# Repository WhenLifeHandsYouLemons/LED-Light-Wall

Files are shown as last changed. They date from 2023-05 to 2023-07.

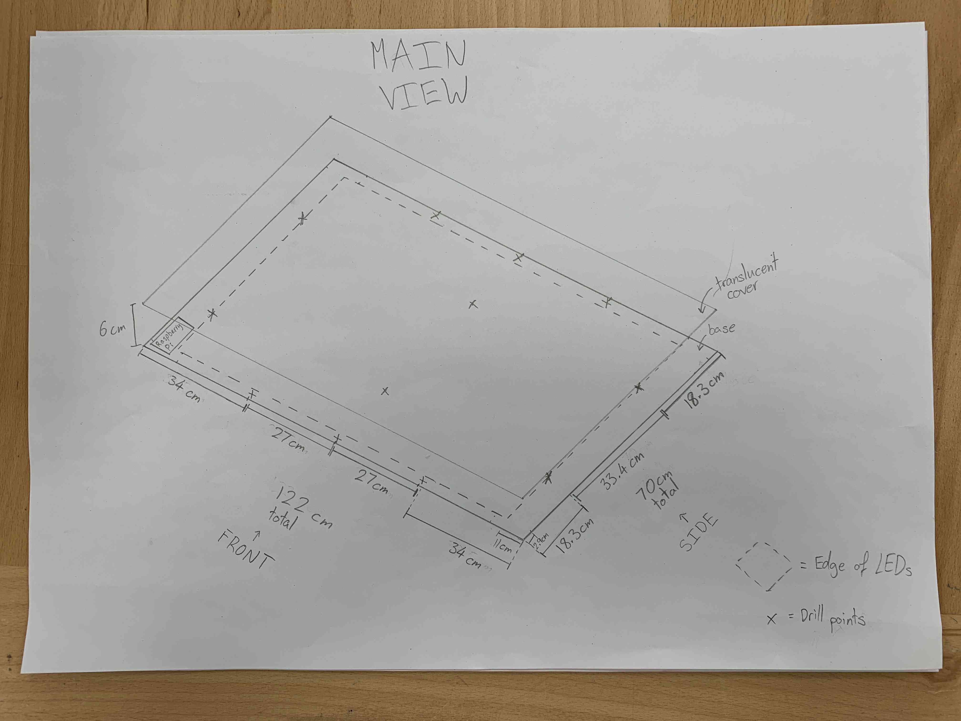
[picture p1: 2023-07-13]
assets/img/thumbnails/v2/designs/designs-2.jpg

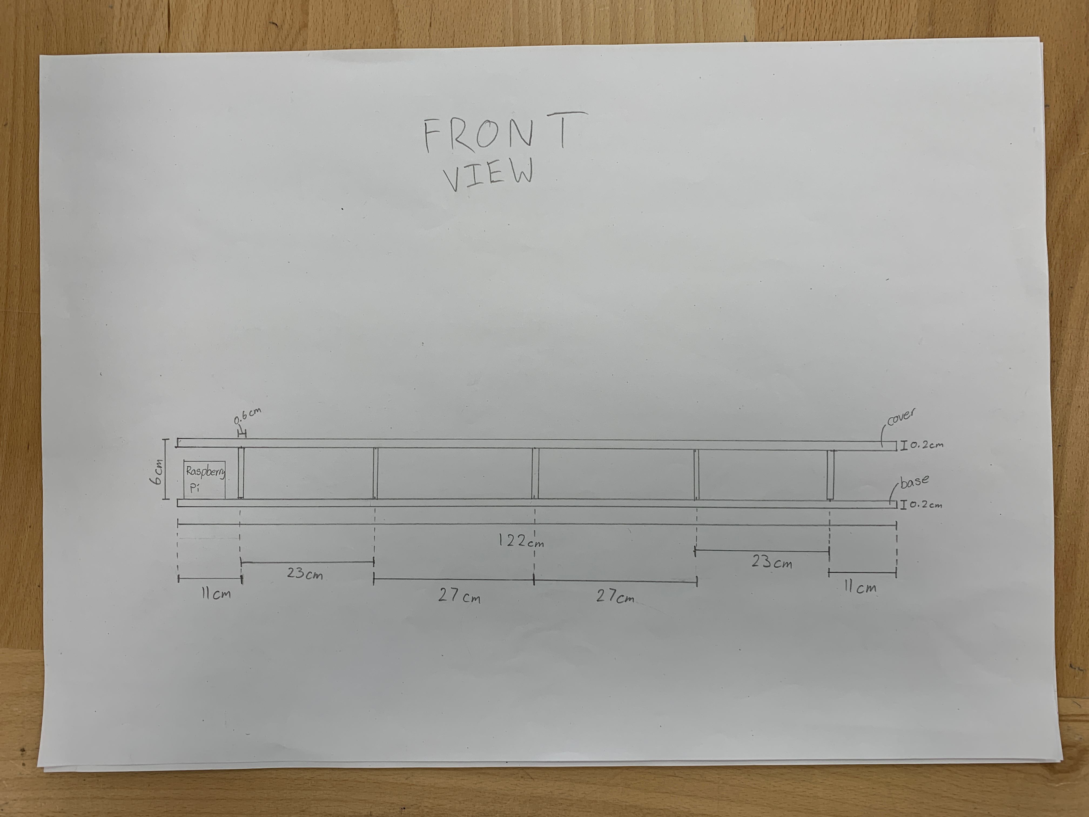
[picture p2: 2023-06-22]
assets/img/fullsize/v2/designs/designs-3.jpg

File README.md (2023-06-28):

# LED Light Wall Project

The documentation for our project is hosted at: "https://whenlifehandsyoulemons.github.io/LED-Light-Wall/".

This project was initially on a private repository and was recently (at the time of writing this) moved into a new public repository for everyone to view!

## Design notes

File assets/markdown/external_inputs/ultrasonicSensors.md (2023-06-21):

# ultrasonicSensors function

## Overview

The `ultrasonicSensors` function reads data from four ultrasonic sensors and calculates the physical position of an object detected by the sensors. It then maps the physical position to the corresponding LED position on a display and displays a wave of light on the LED display.

## Function Signature

```py
def ultrasonicSensors(x: float,
                      y: float) -> Tuple[float, float]:
    pass
```

## Parameters

- `x` = `float`: A float value representing the previous x position of the detected object.
- `y` = `float`: A float value representing the previous y position of the detected object.

## Return Value

- `Tuple[float, float]`: A tuple containing the x and y position of the detected object.

## Function Description

The `ultrasonicSensors` function reads data from four ultrasonic sensors and calculates the physical position of an object detected by the sensors. It then maps the physical position to the corresponding LED position on a display and displays a wave of light on the LED display.

The function starts by storing the previous x and y position values in the `p_x` and `p_y` variables.

It then reads data from four ultrasonic sensors using the `distance` attribute of each sensor object. If any of the sensors detect an object, the function proceeds to calculate the physical position of the detected object.

The physical position is calculated by first normalizing the distance values of the sensors to a range of 0 to 1, where a distance of 1 represents the maximum detection range of the sensor. The x position of the object is then set to the normalized distance value of the first sensor. The y position of the object is set to the minimum normalized distance value of the remaining sensors.

The function then calculates the change in the x and y position values from the previous position values and maps the physical position to the corresponding LED position on the display. The LED position is calculated by multiplying the normalized x and y position values by the total number of LEDs in the x and y directions, respectively, and rounding the result to the nearest integer.

The function then compensates for sensing inaccuracies by adjusting the LED position based on the value of the normalized y position.

Finally, the function displays a wave of light on the LED display using the `displayWave` function, which takes as input a precomputed wave of colors and displays it on the LED display.

## Example Usage

```py
# Initialize the x and y position values
x, y = 0, 0

# Continuously read data from the ultrasonic sensors and display a wave of light on the LED display
while True:
    x, y = ultrasonicSensors(x, y)
```

In the example above, we continuously read data from the ultrasonic sensors and display a wave of light on the LED display using the `ultrasonicSensors` function.

## Exceptions

- The `ultrasonicSensors` function assumes that the ultrasonic sensors are defined properly and can be used to read distance data. If the sensors are not defined properly, the function may not work as expected.

- The `ultrasonicSensors` function assumes that the `displayWave` function is defined properly and can be used to display a wave of light on the LED display. If this function is not defined properly, the function may not work as expected.

- The `ultrasonicSensors` function may not work as expected if there are no objects detected by the sensors or if the sensors detect objects outside their maximum detection range. In this case, the function may not display a wave of light on the LED display or may display an incorrect wave of light.

- The pin wirings of all the ultrasonic sensors are customised for our project. If this doesn't work for you, you can try changing the pin wiring.
  - You can initialise an ultrasonic sensor by writing this line of code: `sensor1 = DistanceSensor(echo=17, trigger=27)`.
  - You can replace 17 and 27 to different pin numbers.

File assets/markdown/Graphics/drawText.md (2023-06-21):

# drawText function

## Overview

The `drawText` function draws text with a specified color at a specified location on a pixel frame buffer. The function outputs the text on the pixel frame buffer.

## Function Signature

```py
def drawText(text: str,
             colour: Tuple[int, int, int],
             x: int,
             y: int = 5) -> None:
    pass
```

## Parameters

- `text` = `(str)`: A string representing the text to be drawn on the pixel frame buffer.

- `x` = `(int)`: An integer representing the x coordinate of the top-left corner of the text.

- `y` = `(int)`: An integer representing the y coordinate of the top-left corner of the text.

- `colour` = `(Tuple[int, int, int])`: A list of three integers representing the RGB color values for the text.

## Return Value

- None

## Function Description

The `drawText` function draws text on a pixel frame buffer using the `text` function from the `pixel_framebuf` library. The function takes in the text to be drawn, the x and y coordinates of the top-left corner of the text, and the RGB color values of the text.

After drawing the text, the function calls the `display` function from the `pixel_framebuf` library to update the pixel frame buffer with the newly drawn text.

Finally, the function completes when the text has been drawn on the pixel frame buffer.

## Example Usage

```py
# Draw the text "Hello, world!" at (5, 5) with the color (255, 0, 0)
drawText("Hello, world!", [255, 0, 0], 5, 5)
```

In the example above, we call the `drawText` function to draw the text "Hello, world!" at $(5, 5)$ with the color $(255, 0, 0)$ on the pixel frame buffer.

## Exceptions

- The `drawText` function assumes that the pixel frame buffer is represented as a rectangular grid of pixels with a width of `board_width` and a height of `board_height`. If the pixel frame buffer is represented differently, the `drawText` function should be modified accordingly.

- The `drawText` function assumes that the RGB color values are integers between 0 and 255. If the RGB color values are represented differently, the `drawText` function should be modified accordingly.

- The `drawText` function assumes that the `text` and `display` functions are defined properly in the `pixel_framebuf` library. If either of these functions is not defined properly, the `drawText` function should be modified accordingly.

- The coordinate system starts from the top left and the first LED is at position $(0, 0)$.

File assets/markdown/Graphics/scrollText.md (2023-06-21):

# scrollText function

## Overview

The `scrollText` function animates text scrolling from right to left on a pixel frame buffer. The function outputs the scrolling text on the pixel frame buffer.

## Function Signature

```py
def scrollText(text: str,
               colour: Tuple[int, int, int],
               wait_time: float,
               end_x: int,
               y: int = 5) -> None:
    pass
```

## Parameters

- `end_x` = `(int)`: An integer representing the x coordinate where the scrolling text will stop.

- `y` = `(int)`: An integer representing the y coordinate of the top-left corner of the scrolling text.

- `text` = `(str)`: A string representing the text to be scrolled on the pixel frame buffer.

- `colour` = `(Tuple[int, int, int])`: A tuple of three integers representing the RGB color values for the scrolling text.

- `wait_time` = `(float)`: A floating-point number representing the duration in seconds between each frame of the scrolling text animation.

## Return Value

- None

## Function Description

The `scrollText` function animates the scrolling text on a pixel frame buffer by repeatedly calling the `drawText` function with different x coordinates. The function takes in the x coordinate where the scrolling text will stop, the y coordinate of the top-left corner of the scrolling text, the text to be scrolled,the RGB color values of the scrolling text, and the duration in seconds between each frame of the scrolling text animation.

The `scrollText` function initializes the x coordinate to be off-screen to the right (`board_width + 1`). Then, it enters a loop where it calls the `drawText` function with the current x coordinate, y coordinate, text, and color. After displaying the text, the function waits for the specified duration using the `time.sleep` function and clears the pixel frame buffer by calling the `setAllPixelsColour` function with the color black. Finally, the function decrements the x coordinate by 1 and repeats the loop until the x coordinate is less than or equal to the specified end_x coordinate.

Once the scrolling text animation is complete, the function completes.

## Example Usage

```py
# Animate scrolling text with the message "Hello, world!" in red
# The scrolling text starts at the right edge of the pixel frame buffer and stops at x = 0
# The scrolling text animation waits for 0.1 seconds between each frame
scrollText("Hello, world!", [255, 0, 0], 0.1, 0, 5)
```

In the example above, we call the `scrollText` function to animate scrolling text with the message "Hello, world!" in red on the pixel frame buffer. The scrolling text starts at the right edge of the pixel frame buffer and stops at $x=0$. The scrolling text animation waits for 0.1 seconds between each frame.

## Exceptions

- The `scrollText` function assumes that the pixel frame buffer is represented as a rectangular grid of pixels with a width of `board_width` and a height of `board_height`. If the pixel frame buffer is represented differently, the `scrollText` function should be modified accordingly.

- The `scrollText` function assumes that the RGB color values are integers between 0 and 255. If the RGB color values are represented differently, the `scrollText` function should be modified accordingly.

- The `scrollText` function assumes that the `drawText`, `time.sleep`, and `setAllPixelsColour` functions are defined properly. If any of these functions is not defined properly, the `scrollText` function should be modified accordingly.

- The coordinate system starts from the top left and the first LED is at position $(0, 0)$.

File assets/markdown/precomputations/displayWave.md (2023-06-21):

# displayWave function

## Overview

The `displayWave` function takes in a wave array (which can be a merged or a single wave array) and displays it on an LED matrix. The function outputs the wave on the LED matrix with a specified delay between each tick.

## Function Signature

```py
def displayWave(wave_array: List[List[List[List[int]]]], delay: float) -> None:
    pass
```

## Parameters

- `wave_array` = `(List[List[List[int, int, List[int, int, int]]]])`: A four-dimensional list representing the LED coordinates and colors for each tick of the wave. Each top-level item in the list represents a wave, and each item in the second-level list represents a tick of the wave. The third-level list contains the x and y coordinates of the LED, and the fourth-level list contains the RGB color values for the LED.

- `delay` = `(float)`: A floating point number representing the delay in seconds between each tick of the wave.

## Return Value

- None

## Function Description

The `displayWave` function loops through each tick in the `wave_array`, and for each tick, it loops through each LED in the tick and sets the color of the corresponding LED on the LED matrix using the `setPixelsColour` function and the `getLED` function.

After setting the colorsof the LEDs for the current tick, the function calls `pixels.show()` to update the display and `time.sleep(delay)` to pause for the specified delay between each tick.

Finally, the function completes when all ticks in all waves in the wave array have been displayed.

## Example Usage

```py
# Display a wave array with a delay of 0.5 seconds between each tick
displayWave(wave_array, 0.5)
```

In the example above, we call the `displayWave` function to display a wave array on an LED matrix with a delay of 0.5 seconds between each tick.

## Exceptions

- The `displayWave` function assumes that the LED display is represented as a rectangular grid of LEDs with a width of `board_width` and a height of `board_height`. If the LED display is represented differently, the `displayWave` function should be modified accordingly.

- The `displayWave` function assumes that all waves in the `wave_array` have the same number of ticks and that each LED is represented as a list with three items: the x and y coordinates, and the RGB color values. If the input wave arrays do not meet these assumptions, the `displayWave` function may not work as expected.

- The `displayWave` function assumes that the RGB color values are integers between 0 and 255. If the RGB color values are represented differently, the `displayWave` function should be modified accordingly.

- The`displayWave` function assumes that the `setPixelsColour` function is defined properly and that it can set the color of a single LED on the LED display. If the `setPixelsColour` function is not defined properly or if the LED display is represented differently, the `displayWave` function should be modified accordingly.

- The `displayWave` function assumes that the `getLED` function is defined properly and that it can return the LED object for a given x and y coordinate on the LED display. If the `getLED` function is not defined properly or if the LED display is represented differently, the `displayWave` function should be modified accordingly.

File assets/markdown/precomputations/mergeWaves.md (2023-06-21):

# mergeWaves function

## Overview

The `mergeWaves` function takes in an array of wave arrays and merges them into a single master array to be displayed. The function outputs a merged wave array with duplicate LED coordinates merged and the colors averaged.

## Function Signature

```py
def mergeWaves(wave_arrays: List[List[List[int, int, List[int, int]]]]) -> List[List[int, int, List[int, int, int]]]:
    pass
```

## Parameters

- `wave_arrays` = `(List[List[List[int, int, List[int, int, int]]]])`: A four-dimensional list representing the LED coordinates and colors for each tick of each wave. Each top-level item in the list represents a wave, and each item in the second-level list represents a tick of the wave. The third-level list contains the x and y coordinates of the LED, and the fourth-level list contains the RGB color values for the LED.

## Return Value

- `merged_wave_array` = `(List[List[int, int, List[int, int, int]]])`: A three-dimensional list representing the merged LED coordinates and colors for each tick of the waves. Each top-level item in the list represents a tick of the wave, and each item in the second-level list represents an LED that should be illuminated for that tick. The third-level list contains the x and y coordinates of the LED, and a list containing the RGB color values for the LED.

## Function Description

The `mergeWaves` function first finds the longest number of ticks across all the input wave arrays. It then makes all the waves have the same number of ticks by appending copies of the last tick to the end of the wave array until it reaches the desired length.

The function then sorts all the LEDs for every wave into one singular array by ticks. It creates a `sorted_wave_array` that contains all the LED coordinates and colors sorted by ticks.

After sorting the LED coordinates, the function merges all duplicates in each tick separately. It creates a `merged_wave_array` that contains the merged LED coordinates and colors for each tick of the waves. The function loops through each tick in the `sorted_wave_array` and merges duplicate LED coordinates by averaging their colors.

The `hasher` function is used to create a hash value for each LED coordinate, which is used to identify duplicates. The function creates a hash table with a fixed number of buckets and merges all duplicates in each tick separately. It creates a new list called merged_wave_array and appends the merged LED coordinates for each tick in the animation to this list.

It keeps track of the used coordinates to avoid merging the same LED multiple times.

Finally, the function returns the `merged_wave_array` with duplicate LED coordinates merged and the colors averaged.

## Example Usage

```py
# Merge wave arrays into a single wave array for display
merged_wave_array = mergeWaves([wave_array1, wave_array2, wave_array3])
```

In the example above, we call the `mergeWaves` function to merge three wave arrays into a single wave array for display.

## Exceptions

- The `mergeWaves` function assumes that the LED display is represented as a rectangular grid of LEDs with a width of `board_width` and a height of `board_height`. If the LED display is represented differently, the`mergeWaves` function should be modified accordingly.

- The `mergeWaves` function assumes that all waves have the same number of LEDs and that each LED is represented as a list with three items: the x and y coordinates, and the RGB color values. If the input wave arrays do not meet these assumptions, the `mergeWaves` function may not work as expected.

- The `mergeWaves` function assumes that the RGB color values are integers between 0 and 255. If the RGB color values are represented differently, the `mergeWaves` function should be modified accordingly.

- The `mergeWaves` function assumes that the `setPixelColour` function is defined properly and that it can set the color of a single LED on the LED display. If the `setPixelColour` function is not defined properly or if the LED display is represented differently, the `mergeWaves` function should be modified accordingly.

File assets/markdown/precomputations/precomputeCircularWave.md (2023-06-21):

# precomputeCircularWave function

## Overview

The `precomputeCircularWave` function computes an array of LED coordinates for each tick of a circular wave, given the starting LED coordinates and the duration of the wave. The function uses the Bresenham Circle Algorithm to calculate the coordinates of the LEDs that should be illuminated for each tick of the wave. The resulting array can be used to display the wave on an LED display.

## Function Signature

```py
def precomputeCircularWave(x: int,
                           y: int,
                           duration: int) -> List[List[List[int, int]]]:
    pass
```

## Parameters

- `x` = `(int)`: An integer representing the x-coordinate of the center of the circular wave.

- `y` = `(int)`: An integer representing the y-coordinate of the center of the circular wave.

- `duration` = `(int)`: An integer representing the duration of the wave in ticks.

## Return Value

- `List[List[List[int, int]]]`: A three-dimensional list representing the LED coordinates for each tick of the wave. Each top-level item in the list represents a tick of the wave, and each item in the second-level list represents an LED that should be illuminated for that tick. The third-level list contains the x and y coordinates of the LED.

## Function Description

The `precomputeCircularWave` function computes an array of LED coordinates for each tick of a circular wave, given the starting LED coordinates and the duration of the wave. The function first creates an empty list called `precomputed_wave` to store the LED coordinates for each tick of the wave.

The function then hard-codes the first tick of the wave by adding the starting LED coordinates to the first item of `precomputed_wave`.

For each subsequent tick of the wave, the function uses the Bresenham Circle Algorithm to calculate the coordinates of the LEDs that should be illuminated. The algorithm computes the coordinates of the LEDs in the first octant of the circle and then mirrors these coordinates in the other octants.

The function then adds the mirrored coordinates to the `tick_array` list. The `offset_x` and `offset_y` variables are used to adjust the coordinates of the LEDs to the correct position relative to the center of the circle.

The function then removes any duplicate LEDs from the `tick_array` list. This is done to avoid illuminating the same LED multiple times in the same tick.

Finally, the `tick_array` is added to the `precomputed_wave` list, and the function returns the `precomputed_wave` list.

## Example Usage

```py
# Compute precomputed_wave for a circular wave centered at LED (0, 0) with a duration of 5 ticks
precomputed_wave = precomputeCircularWave(0, 0, 5)
```

In the example above, we call the `precomputeCircularWave` function to compute an array of LED coordinates for a circular wave centered at LED $(0, 0)$ with a duration of 5 ticks.

## Exceptions

- The `precomputeCircularWave` function assumes that the LED display is represented as a rectangular grid of LEDs with a width of `board_width` and a height of `board_height`. If the LED display is represented differently, the `precomputeCircularWave` function should be modified accordingly.

- The `precomputeCircularWave` function assumes that the `board_width` and `board_height` constants are defined properly. If these constants are not defined properly, the `precomputeCircularWave` function may not work as expected.

- The `precomputeCircularWave` function assumes that the `setPixelColour` function is defined properly and that it can set the color of a single LED on the LED display. If the `setPixelColour` function is not defined properly or if the LED display is represented differently, the `precomputeCircularWave` function should be modified accordingly.

- The `precomputeCircularWave` function may be computationally expensive for durations of over 60 ticks, as noted in the function's comments. If the duration of the wave is expected to be longer than 60 ticks, the function may need to be optimized or replaced with a more efficient algorithm.

- The coordinate system starts from the bottom left and the first LED is at position $(0, 0)$.

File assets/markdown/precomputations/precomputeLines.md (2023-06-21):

# precomputeLines function

## Overview

The `precomputeLines` function computes an array of LED coordinates for a singular straight line pattern, given the starting and ending center coordinates of the line, as well as the width of the line. The function uses the Bresenham's Line Algorithm to calculate the coordinates of the LEDs that should be illuminated for each point on the line. The resulting array can be used to display the line on an LED display.

## Function Signature

```py
def precomputeLines(x: int,
                    y: int,
                    e_x: int,
                    e_y: int,
                    width: int) -> List[List[List[int, int]]]:
    pass
```

## Parameters

- `x` = `(int)`: An integer representing the x-coordinate of the starting center of the line.

- `y` = `(int)`: An integer representing the y-coordinate of the starting center of the line.

- `e_x` = `(int)`: An integer representing the x-coordinate of the ending center of the line.

- `e_y` = `(int)`: An integer representing the y-coordinate of the ending center of the line.

- `width` = `(int)`: An integer representing the width of the line, in LEDs.

## Return Value

- `List[List[List[int, int]]]`: A three-dimensional list representing the LED coordinates for each point on the line. Each top-level item in the list represents a point on the line, and each item in the second-level list represents an LED that should be illuminated for that point. The third-level list contains the x and y coordinates of the LED.

## Function Description

The `precomputeLines` function computes an array of LED coordinates for a singular straight line pattern, given the starting and ending center coordinates of the line, as well as the width of the line.

The function calculates the slope of the line, `m`, then checks whether the line has a steep or shallow gradient. If it's shallow, then the function will iterate over the x-coordinates of the line. Otherwise, the function will iterate over the y-coordinates of the line.

For each point on the line, the function uses the Bresenham's Line Algorithm to calculate the coordinates of the LEDs that should be illuminated for that point.

## Example Usage

```py
# Compute precomputed_wave for a singular straight line from (0, 0) to (5, 5) with a width of 3 LEDs
precomputed_wave = precomputeLines(0, 0, 5, 5, 3)
```

In the example above, we call the `precomputeLines` function to compute an array of LED coordinates for a singular straight line from $(0, 0)$ to $(5, 5)$ with a width of 3 LEDs.

## Exceptions

- The `precomputeLines` function assumes that the LED display is represented as a rectangular grid of LEDs with a width of `board_width` and a height of `board_height`. If the LED display is represented differently, the `precomputeLines` function should be modified accordingly.

- The `precomputeLines` function assumes that the `board_width` and `board_height` constants are defined properly. If these constants are not defined properly, the `precomputeLines` function may not work as expected.

- The `precomputeLines` function assumes that the `setPixelColour` function is defined properly and that it can set the color of a single LED on the LED display. If the `setPixelColour` function is not defined properly or if the LED display is represented differently, the `precomputeLines` function should be modified accordingly.

- The `precomputeLines` function uses the Bresenham's Line Algorithm to calculate the coordinates of the LEDs that should be illuminated for each point on the line. While this algorithm is efficient, it may not produce perfectly straight lines in some cases. If perfectly straight lines are required, a different algorithm may need to be used.

- The `precomputeLines` function may not work as expected if the starting and ending coordinates of the line do not form a straight line. In this case, the resulting LED coordinates may not form a straight line on the LED display.

- The `precomputeLines` function assumes that the width of the line is an odd integer. If an even integer is supplied, the function will round down to the nearest odd integer.

- The `precomputeLines` function assumes that the starting and ending coordinates of the line are within the bounds of the LED display. If the coordinates are outside the bounds of the LED display, the function may not work as expected.

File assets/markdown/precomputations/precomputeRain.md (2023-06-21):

# precomputeRain function

## Overview

The `precomputeRain` function computes an array of LED coordinates for a singular raindrop pattern, given the starting x-coordinate of the raindrop. The function returns the coordinates of the raindrop for a fixed duration of 20 ticks.

## Function Signature

```py
def precomputeRain(x: int) -> List[List[List[int, int]]]:
    pass
```

## Parameters

- `x` = `(int)`: An integer representing the x-coordinate of the top of the raindrop.

## Return Value

- `List[List[List[int, int]]]`: A three-dimensional list representing the LED coordinates for each tick of the raindrop. Each item in the list represents a tick of the raindrop, and each item in the second-level list represents an LED that should be illuminated for that tick. The third-level list contains the x and y coordinates of the LED.

## Function Description

The `precomputeRain` function computes an array of LED coordinates for a singular raindrop pattern, given the starting x-coordinate of the raindrop. The function first sets the duration of the raindrop to 20 ticks and initializes the y-coordinate of the top of the raindrop to 19.

The function then creates an empty list called `precomputed_wave` to store the LED coordinates for each tick of the raindrop. The x and y coordinates of the top of the raindrop are added to the first item of `precomputed_wave`.

For each subsequent tick of the raindrop, the function decrements the y-coordinate of the top of the raindrop by 1 and adds the new coordinates to the `precomputed_wave` list.

Finally, the function returns the `precomputed_wave` list.

## Example Usage

```py
# Compute precomputed_wave for a singular raindrop starting at x=5
precomputed_wave = precomputeRain(5)
```

In the example above, we call the `precomputeRain` function to compute an array of LED coordinates for a singular raindrop starting at $x=5$.

## Exceptions

- The `precomputeRain` function assumes that the LED display is represented as a rectangular grid of LEDs with a width of `board_width` and a height of `board_height`. If the LED display is represented differently, the `precomputeRain` function should be modified accordingly.

- The `precomputeRain` function assumes that the `board_width` and `board_height` constants are defined properly. If these constants are not defined properly, the `precomputeRain` function may not work as expected.

- The `precomputeRain` function assumes that the `setPixelColour` function is defined properly and that it can set the color of a single LED on the LED display. If the `setPixelColour` function is not defined properly or if the LED display is represented differently, the `precomputeRain` function should be modified accordingly.

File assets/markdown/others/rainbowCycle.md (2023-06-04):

# rainbowCycle function

```py
from rainbowio import colorwheel

def rainbowCycle(wait):
    for j in range(255):
        for i in range(num_pixels):
            rc_index = (i * 256 // num_pixels) + j
            pixels[i] = colorwheel(rc_index & 255)
        pixels.show()
        time.sleep(wait)

while True:
    rainbowCycle(0.1)
```

This function sets all the LEDs to a rainbow colour, it then moves through the LEDs creating a rainbow cycle. This section of code can be copy and pasted as an experiment.

This function requires the NeoPixel library.

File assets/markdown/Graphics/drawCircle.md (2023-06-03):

# drawCircle function

## Overview

The `drawCircle` function draws a circle with a specified center point, radius, and color on a pixel frame buffer. The function outputs the circle on the pixel frame buffer.

## Function Signature

```py
def drawCircle(x: int,
               y: int,
               radius: int,
               colour: Tuple[int, int, int]) -> None:
    pass
```

## Parameters

- `x` = `(int)`: An integer representing the x coordinate of the center of the circle.

- `y` = `(int)`: An integer representing the y coordinate of the center of the circle.

- `radius` = `(int)`: An integer representing the radius of the circle.

- `colour` = `(Tuple[int, int, int])`: A tuple of three integers representing the RGB color values for the circle.

## Return Value

- None

## Function Description

The `drawCircle` function draws a circle on a pixel frame buffer using the `circle` function from the `pixel_framebuf` library. The function takes in the x and y coordinates of the center of the circle, the radius of the circle, and the RGB color values of the circle.

After drawing the circle, the function calls the `display` function from the `pixel_framebuf` library to update the pixel frame buffer with the newly drawn circle.

Finally, the function completes when the circlehas been drawn on the pixel frame buffer.

## Example Usage

```py
# Draw a circle with center at (10, 10), radius of 5, and color (255, 0, 0)
drawCircle(10, 10, 5, [255, 0, 0])
```

In the example above, we call the `drawCircle` function to draw a circle with a center at $(10, 10)$, radius of 5, and color $(255, 0, 0)$ on the pixel frame buffer.

## Exceptions

- The `drawCircle` function assumes that the pixel frame buffer is represented as a rectangular grid of pixels with a width of `board_width` and a height of `board_height`. If the pixel frame buffer is represented differently, the `drawCircle` function should be modified accordingly.

- The `drawCircle` function assumes that the RGB color values are integers between 0 and 255. If the RGB color values are represented differently, the `drawCircle` function should be modified accordingly.

- The `drawCircle` function assumes that the `circle` and `display` functions are defined properly in the `pixel_framebuf` library. If either of these functions is not defined properly, the `drawCircle` function should be modified accordingly.

- The coordinate system starts from the top left and the first LED is at position $(0, 0)$.

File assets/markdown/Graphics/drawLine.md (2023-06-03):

# drawLine function

## Overview

The `drawLine` function draws a single line between two points with a specified color on a pixel frame buffer. The function outputs the line on the pixel frame buffer.

## Function Signature

```py
def drawLine(start_x: int,
             start_y: int,
             end_x: int,
             end_y: int,
             colour: Tuple[int, int, int]) -> None:
    pass
```

## Parameters

- `start_x` = `(int)`: An integer representing the x coordinate of the start point of the line.

- `start_y` = `(int)`: An integer representing the y coordinate of the start point of the line.

- `end_x` = `(int)`: An integer representing the x coordinate of the end point of the line.

- `end_y` = `(int)`: An integer representing the y coordinate of the end point of the line.

- `colour` = `(Tuple[int, int, int])`: A tuple of three integers representing the RGB color values for the line.

## Return Value

- None

## Function Description

The `drawLine` function draws a single line between two points on a pixel frame buffer using the `line` function from the `pixel_framebuf` library. The function takes in the x and y coordinates of the start and end points of the line, as well as the RGB color values of the line.

After drawing the line, the function calls the `display` function from the `pixel_framebuf` library to update the pixel frame buffer with the newly drawn line.

Finally, the function completes when the line has been drawn on the pixel frame buffer.

## Example Usage

```py
# Draw a line from (0, 0) to (10, 10) with the color (255, 0, 0)
drawLine(0, 0, 10, 10, [255, 0, 0])
```

In the example above, we call the `drawLine` function to draw a line from the point $(0, 0)$ to the point $(10, 10)$ with the color $(255, 0, 0)$ on the pixel frame buffer.

## Exceptions

- The `drawLine` function assumes that the pixel frame buffer is represented as a rectangular grid of pixels with a width of `framebuf_width` and a height of `framebuf_height`. If the pixel frame buffer is represented differently, the `drawLine` function should be modified accordingly.

- The `drawLine` function assumes that the RGB color values are integers between 0 and 255. If the RGB color values are represented differently, the `drawLine` function should be modified accordingly.

- The `drawLine` function assumes that the `line` and `display` functions are defined properly in the `pixel_framebuf` library. If either of these functions is not defined properly, the `drawLine` function should be modified accordingly.

- The coordinate system starts from the top left and the first LED is at position $(0, 0)$.

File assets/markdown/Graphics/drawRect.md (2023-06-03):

# drawRect function

## Overview

The `drawRect` function draws a rectangle with a specified width, height, color, and style on a pixel frame buffer. The function outputs the rectangle on the pixel frame buffer.

## Function Signature

```py
def drawRect(x: int,
             y: int,
             width: int,
             height: int,
             colour: Tuple[int, int, int],
             filled: bool) -> None:
    pass
```

## Parameters

- `x` = `(int)`: An integer representing the x coordinate of the top-left corner of the rectangle.

- `y` = `(int)`: An integer representing the y coordinate of the top-left corner of the rectangle.

- `width` = `(int)`: An integer representing the width of the rectangle.

- `height` = `(int)`: An integer representing the height of the rectangle.

- `colour` = `(Tuple[int, int, int])`: A tuple of three integers representing the RGB color values for the rectangle.

- `filled` = `(bool)`: A boolean value representing the style of the rectangle. If `filled` is `True`, the rectangle is filled; otherwise, it is hollow.

## Return Value

- None

## Function Description

The `drawRect` function draws a rectangle on a pixel frame buffer using the `rect` or `fill_rect` function from the `pixel_framebuf` library. The functiontakes in the x and y coordinates of the top-left corner of the rectangle, the width and height of the rectangle, the RGB color values of the rectangle, and a boolean value representing the style of the rectangle.

If `filled` is `True`, the function draws a filled rectangle using the `fill_rect` function. Otherwise, the function draws a hollow rectangle using the `rect` function.

After drawing the rectangle, the function calls the `display` function from the `pixel_framebuf` library to update the pixel frame buffer with the newly drawn rectangle.

Finally, the function completes when the rectangle has been drawn on the pixel frame buffer.

## Example Usage

```py
# Draw a filled rectangle starting at (5, 5) with a width of 10, a height of 15, and the color (255, 0, 0)
drawRect(5, 5, 10, 15, [255, 0, 0], True)

# Draw a hollow rectangle starting at (0, 0) with a width of 20, a height of 10, and the color (0, 255, 0)
drawRect(0, 0, 20, 10, [0, 255, 0], False)
```

In the examples above, we call the `drawRect` function to draw a filled rectangle starting at $(5, 5)$ with a width of 10, a heightof 15, and the color $(255, 0, 0)$ and to draw a hollow rectangle starting at $(0, 0)$ with a width of 20, a height of 10, and the color $(0, 255, 0)$ on the pixel frame buffer.

## Exceptions

- The `drawRect` function assumes that the pixel frame buffer is represented as a rectangular grid of pixels with a width of `board_width` and a height of `board_height`. If the pixel frame buffer is represented differently, the `drawRect` function should be modified accordingly.

- The `drawRect` function assumes that the RGB color values are integers between 0 and 255. If the RGB color values are represented differently, the `drawRect` function should be modified accordingly.

- The `drawRect` function assumes that the `rect`, `fill_rect`, and `display` functions are defined properly in the `pixel_framebuf` library. If any of these functions is not defined properly, the `drawRect` function should be modified accordingly.

- The coordinate system starts from the top left and the first LED is at position $(0, 0)$.

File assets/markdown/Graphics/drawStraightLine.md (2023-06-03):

# drawStraightLine function

## Overview

The `drawStraightLine` function draws a straight line with a specified length, color, and orientation on a pixel frame buffer. The function outputs the line on the pixel frame buffer.

## Function Signature

```py
def drawStraightLine(x: int,
                     y: int,
                     length: int,
                     colour: Tuple[int, int, int],
                     horizontal: bool) -> None:
    pass
```

## Parameters

- `x` = `(int)`: An integer representing the x coordinate of the start point of the line.

- `y` = `(int)`: An integer representing the y coordinate of the start point of the line.

- `length` = `(int)`: An integer representing the length of the line.

- `colour` = `(Tuple[int, int, int])`: A tuple of three integers representing the RGB color values for the line.

- `horizontal` = `(bool)`: A boolean value representing the orientation of the line. If `horizontal` is `True`, the line is horizontal; otherwise, it is vertical.

## Return Value

- None

## Function Description

The `drawStraightLine` function draws a straight line on a pixel frame buffer using the `hline` or `vline` function from the `pixel_framebuf` library. The function takes in the x and y coordinates of the start point of the line,the length of the line, the RGB color values of the line, and a boolean value representing the orientation of the line.

If `horizontal` is `True`, the function draws a horizontal line from left to right using the `hline` function. Otherwise, the function draws a vertical line from top to bottom using the `vline` function.

After drawing the line, the function calls the `display` function from the `pixel_framebuf` library to update the pixel frame buffer with the newly drawn line.

Finally, the function completes when the line has been drawn on the pixel frame buffer.

## Example Usage

```py
# Draw a horizontal line starting at (0, 0) with a length of 10 and the color (255, 0, 0)
drawStraightLine(0, 0, 10, [255, 0, 0], True)

# Draw a vertical line starting at (5, 5) with a length of 15 and the color (0, 255, 0)
drawStraightLine(5, 5, 15, [0, 255, 0], False)
```

In the examples above, we call the `drawStraightLine` function to draw a horizontal line starting at $(0, 0)$ with a length of 10 and the color $(255, 0, 0)$ and to draw a vertical line starting at $(5, 5)$ with a lengthof 15 and the color $(0, 255, 0)$ on the pixel frame buffer.

## Exceptions

- The `drawStraightLine` function assumes that the pixel frame buffer is represented as a rectangular grid of pixels with a width of `board_width` and a height of `board_height`. If the pixel frame buffer is represented differently, the `drawStraightLine` function should be modified accordingly.

- The `drawStraightLine` function assumes that the RGB color values are integers between 0 and 255. If the RGB color values are represented differently, the `drawStraightLine` function should be modified accordingly.

- The `drawStraightLine` function assumes that the `hline`, `vline`, and `display` functions are defined properly in the `pixel_framebuf` library. If any of these functions is not defined properly, the `drawStraightLine` function should be modified accordingly.

- The coordinate system starts from the top left and the first LED is at position $(0, 0)$.

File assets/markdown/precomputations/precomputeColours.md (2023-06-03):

# precomputeColours function

## Overview

The `precomputeColours` function takes in a precomputed wave array and calculates an array of crest and fade colors for each LED in the wave. The function outputs the updated wave array with crest and fade colors included.

## Function Signature

```python
def precomputeColours(input_wave: List[List[List[int, int]]],
                      i_color: List[int, int, int],
                      e_color: List[int, int, int],
                      fade: int
                      ) -> List[List[List[int, int, List[int, int, int]]]]:
    pass
```

## Parameters

- `input_wave` = `(List[List[List[int, int]]])`: A three-dimensional list representing the LED coordinates for each tick of the wave.

- `i_color` = `(List[int, int, int])`: A list representing the initial color of the crest in RGB format.

- `e_color` = `(List[int, int, int])`: A list representing the end color of the crest in RGB format.

- `fade` = `(int)`: An integer representing the duration of the fade in ticks.

## Return Value

- `List[List[int, int, List[int, int, int]]]`: A four-dimensional list representing the LED coordinates and colors for each tick of the wave, including crest and fade colors. Each top-level item in the list represents a tick of the wave, and each item in the second-level list represents an LED that should be illuminated for that tick. The third-level listcontains the x and y coordinates of the LED, and a list that contains the RGB color values for the LED.

## Function Description

The `precomputeColours` function first creates a deep copy of the input wave array to avoid modifying the original values. The function then calculates the crest colors for each tick of the wave based on the initial and end colors provided as input.

To calculate the crest colors, the function computes the shift in color for each RGB component per tick, based on the difference between the initial and end colors and the duration of the wave. The function then extends the input wave array to include the crest colors for each LED at each tick.

After computing the crest colors, the function calculates the fade colors for each LED in the wave. The function first adds additional ticks to the wave array to account for the duration of the fade. For each tick in the wave array, the function calculates the fade color for each LED based on the difference between the crest color and the end color, and the duration of the fade.

The function stores the faded LED coordinates and colors in a separate list called `faded_LEDS`. The function then loops through the `faded_LEDS` list and adds the faded LED coordinates and colors to the appropriate tick in the original wave array.

Finally, the function adds all previous tick's LEDs without changing their color to have accurate color mixing. The function returns the updated wave array with crest and fade colors included.

## Example Usage

```py
# Compute precomputed_wave with crest and fade colors for a wave moving from up to down with a duration of 5 ticks, initial color of (255, 0, 0), end color of (0, 255, 0), and a fade duration of 2 ticks
precomputed_wave_with_colour = precomputeColours(precomputed_wave, [255, 0, 0], [0, 255, 0], 2)
```

In the example above, we call the `precomputeColours` function to calculate the crest and fade colors for a precomputed wave array representing a wave moving from up to down with a duration of 5 ticks, an initial color of $(255, 0, 0)$, an end color of $(0, 255, 0)$, and a fade duration of 2 ticks.

## Exceptions

- The `precomputeColours` function assumes that the LED display is represented as a rectangular grid of LEDs with a width of `board_width` and a height of `board_height`. If the LED display is represented differently, the `precomputeColours` function should be modified accordingly.

- The `precomputeColours` function assumes that the `board_width` and `board_height` constants are defined properly. If these constants are not defined properly, the `precomputeColours` function may not work as expected.

- The `precomputeColours` function assumes that the `setPixelColour`function is defined properly and that it can set the color of a single LED on the LED display. If the `setPixelColour` function is not defined properly or if the LED display is represented differently, the `precomputeColours` function should be modified accordingly.

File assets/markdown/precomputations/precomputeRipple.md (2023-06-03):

# precomputeRipple function

## Overview

The `precomputeRipple` function computes an array of LED coordinates for each tick of a wave, given the starting LED coordinates and the duration of the wave. The function uses a simple algorithm to calculate the coordinates of each LED that should be illuminated for each tick of the wave. The resulting array can be used to display the wave on an LED display.

## Function Signature

```py
def precomputeRipple(x: int,
                     y: int,
                     duration: int) -> List[List[List[int, int]]]:
    pass
```

## Parameters

- `x` = `(int)`: An integer representing the x-coordinate of the starting LED.

- `y` = `(int)`: An integer representing the y-coordinate of the starting LED.

- `duration` = `(int)`: An integer representing the duration of the wave in ticks.

## Return Value

- `List[List[List[int, int]]]`: A three-dimensional list representing the LED coordinates for each tick of the wave. Each top-level item in the list represents a tick of the wave, and each item in the second-level list represents an LED that should be illuminated for that tick. The third-level list contains the x and y coordinates of the LED.

## Function Description

The `precomputeRipple` function computes anarray of LED coordinates for each tick of a wave, given the starting LED coordinates and the duration of the wave. The function first creates an empty list called `precomputed_wave` to store the LED coordinates for each tick of the wave.

The function then adds the starting LED coordinates to the first item of `precomputed_wave`, representing the first tick of the wave.

For each subsequent tick of the wave, the function loops through the LED coordinates for the previous tick and calculates the coordinates of each LED that should be illuminated for the next tick. The function stores these coordinates in a new list called `tick_array`, and adds `tick_array` to `precomputed_wave`.

The function uses the `used_leds` list to keep track of which LEDs have already been included in previous ticks, to avoid duplicates. The function checks the LED to the left, right, above, and below each LED in the previous tick, and adds any new LEDs to `tick_array` if they meet the criteria. The function then adds these new LEDs to `used_leds` to avoid duplicates.

The function returns the `precomputed_wave` list, which contains the LED coordinates for each tick of the wave.

## Example Usage

```py
# Compute precomputed_wave for a wave starting at LED (0, 0) with a duration of 5 ticks
precomputed_wave = precomputeRipple(0, 0, 5)
```

In the example above, we call the`precomputeRipple` function to compute an array of LED coordinates for a wave starting at LED $(0, 0)$ with a duration of 5 ticks.

## Exceptions

- The `precomputeRipple` function assumes that the LED display is represented as a rectangular grid of LEDs with a width of `board_width` and a height of `board_height`. If the LED display is represented differently, the `precomputeRipple` function should be modified accordingly.

- The `precomputeRipple` function assumes that the `board_width` and `board_height` constants are defined properly. If these constants are not defined properly, the `precomputeRipple` function may not work as expected.

- The `precomputeRipple` function assumes that the `setPixelColour` function is defined properly and that it can set the color of a single LED on the LED display. If the `setPixelColour` function is not defined properly or if the LED display is represented differently, the `precomputeRipple` function should be modified accordingly.

- The `precomputeRipple` function may be computationally expensive for durations of over 60 ticks, as noted in the function's comments. If the duration of the wave is expected to be longer than 60 ticks, the function may need to be optimized or replaced with a more efficient algorithm.

- The coordinate system starts from the bottom left and the first LED is at position $(0, 0)$.

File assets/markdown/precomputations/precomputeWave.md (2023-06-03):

# precomputeWave function

## Overview

The `precomputeWave` function computes an array of LED coordinates for a wave moving in a specified direction, given the starting position and the duration of the wave. The function outputs the LED coordinates in the same format as `precomputeRipple` so that `precomputeColours` can be used on the output.

## Function Signature

```py
def precomputeWave(pos: int,
                   duration: int) -> List[List[List[int, int]]]:
    pass
```

## Parameters

- `pos` = `(int)`: An integer representing the direction of the wave. The possible values of `pos` are:
  - 0 = Up to down
  - 1 = Right to left
  - 2 = Down to up
  - 3 = Left to right

- `duration` = `(int)`: An integer representing the duration of the wave in ticks.

## Return Value

- `List[List[List[int, int]]]`: A three-dimensional list representing the LED coordinates for each tick of the wave. Each top-level item in the list represents a tick of the wave, and each item in the second-level list represents an LED that should be illuminated for that tick. The third-level list contains the x and y coordinates of the LED.

## Function Description

The `precomputeWave` function computes an array of LED coordinates for a wave moving in a specified direction, given the starting position and the duration of the wave. The function first creates an empty list called `precomputed_wave` to store the LED coordinates for each tick of the wave.

The function then uses a series of conditional statements to determine the starting LED coordinates based on the direction of the wave (`pos`). The function adds these starting coordinates to the first item of `precomputed_wave`.

For each subsequent tick of the wave, the function loops through the LED coordinates for the previous tick and calculates the coordinates of each LED that should be illuminated for the next tick. The function stores these coordinates in a new list called `tick_array`, and adds `tick_array` to `precomputed_wave`.

The function uses simple arithmetic to calculate the coordinates of each LED based on the direction of the wave (`pos`). For example, if the wave is moving from left to right (`pos = 3`), the function increments the x-coordinate of each LED in the previous tick by 1. The function then adds `tick_array` to `precomputed_wave`.

The function returns the `precomputed_wave` list, which contains the LED coordinates for each tick of the wave.

## Example Usage

```py
# Compute precomputed_wave for a wave moving from up to down with a duration of 5 ticks
precomputed_wave = precomputeWave(0, 5)
```

In the example above, we call the `precomputeWave` function to compute an array of LED coordinates for a wave moving from up to down with a duration of 5 ticks.

## Exceptions

- The `precomputeWave` function assumes that the LED display is represented as a rectangular grid of LEDs with a width of `board_width` and a height of `board_height`. If the LED display is represented differently, the `precomputeWave` function should be modified accordingly.

- The `precomputeWave` function assumes that the `board_width` and `board_height` constants are defined properly. If these constants are not defined properly, the `precomputeWave` function may not work as expected.

- The `precomputeWave` function assumes that the `setPixelColour` function is defined properly and that it can set the color of a single LED on the LED display. If the `setPixelColour` function is not defined properly or if the LED display is represented differently, the `precomputeWave` function should be modified accordingly.

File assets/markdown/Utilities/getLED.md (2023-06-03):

# getLED function

## Overview

The `getLED` function takes two integer inputs, `input_x` and `input_y`, and returns an integer output representing the number of an LED based on the given X and Y coordinates. This function is useful for applications that require mapping LED coordinates to LED numbers.

## Function Signature

```py
def getLED(input_x: int,
           input_y: int) -> int:
    pass
```

## Parameters

- `input_x` = `(int)`: The X coordinate of the LED. This must be an integer.
- `input_y` = `(int)`: The Y coordinate of the LED. This must be an integer.

## Return Value

- `int`: The number of the LED based on the given X and Y coordinates. This is an integer value.

## Function Description

The `getLED` function takes in two integer inputs, `input_x` and `input_y`, which represent the X and Y coordinates of the LED, respectively. The function calculates the number of the LED based on these coordinates and returns it as an integer value.

The function first calculates the output variable as `input_y * board_width`. Then, based on the parity of `input_y`, the function determines whether to count from left to right or right to left on the row. If `input_y` is even,the function counts from left to right (i.e., `right_direction` is True), and if `input_y` is odd, the function counts from right to left (i.e., `right_direction` is False).

If `right_direction` is True, the function adds `input_x` to the output variable. Otherwise, the function adds `((board_width - 1) - input_x)` to the output variable. Finally, the function returns the output variable plus 1 (to account for the fact that LED numbering starts at 1, not 0).

## Example Usage

```py
# Set the board width
board_width = 8

# Get the LED number for X=2, Y=3
led_number = getLED(2, 3)

print(led_number)  # Output: 22
```

In the example above, we set the `board_width` variable to 8 and call the `getLED` function with `input_x` equal to 2 and `input_y` equal to 3. The function returns the number of the LED at those coordinates, which is 22. We then print the value of `led_number`, which outputs `22`.

## Exceptions

- `TypeError`: If either `input_x` or `input_y` is not an integer, a `TypeError` is raised.

## Notes

- This function assumes that the `board_width` variable has been set to the correct valuefor the board being used. If `board_width` is not set or is set incorrectly, the function may return an incorrect LED number.

- This function assumes that the LED numbering starts at 1 and not 0. If the LED numbering starts at a different value, the function should be modified accordingly.

- The `getLED` function does not perform any error checking on the input values beyond checking that they are integers. It is the responsibility of the calling code to ensure that the input values are within the appropriate range for the LED board being used.

- The coordinate system starts from the bottom left and the first LED is at position $(0, 0)$.

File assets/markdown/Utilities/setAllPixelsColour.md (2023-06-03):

# setAllPixelsColour function

## Overview

The `setAllPixelsColour` function takes an RGB color as a tuple of three integers, sets all pixels to the specified color, and updates the LED display. This function is useful for applications that require setting the color of the entire LED display.

## Function Signature

```py
def setAllPixelsColour(colour: Tuple[int, int, int]) -> None:
    pass
```

## Parameters

- `colour` = `(Tuple[int, int, int])`: A tuple of three integers representing the RGB color. The first integer represents the red component, the second integer represents the green component, and the third integer represents the blue component. Each component must be an integer between 0 and 255, inclusive.

## Return Value

- None

## Function Description

The `setAllPixelsColour` function takes an RGB color as a tuple of three integers, `colour`, which represents the color to set all the pixels to. The function sets all pixels to the specified color and updates the LED display.

The function first calls the `RGBToHex` function to convert the `colour` tuple to its corresponding hexadecimal value. The function then uses the `fill()` method of the `pixel_framebuf` object to set all pixels to the specified color, and the `display()` method to update the LED display with the new color.

## Example Usage

```py
# Set all pixels to red
setAllPixelsColour((255, 0, 0))
```

In the example above, we call the `setAllPixelsColour` function with the tuple `(255, 0, 0)`, which represents the RGB color red. The function sets all pixels to red and updates the LED display.

## Exceptions

- `TypeError`: If the `colour` parameter is not a tuple of three integers, a `TypeError` is raised.

- `ValueError`: If any of the color components in the `colour` tuple is not an integer between 0 and 255, inclusive, a `ValueError` is raised.

## Notes

- The `setAllPixelsColour` function assumes that the LED display is represented by the `pixel_framebuf` object and that it has the `fill()` and `display()` methods. If the LED display is represented differently or if the display methods have different names, the function should be modified accordingly.

- The `setAllPixelsColour` function does not perform any error checking beyond checking that the `colour` parameter is a tuple of three integers. It is the responsibility of the calling code to ensure that the input color is valid and within the appropriate range for the RGB color space.

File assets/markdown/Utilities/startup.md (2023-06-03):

# startup function

## Overview

The `startup` function is a utility function that sets the color of all pixels on the LED display to each of the colors in the `colours` dictionary in sequence. This function is useful for verifying that the LED display is working properly and that the colors are being displayed correctly.

## Function Signature

```py
def startup() -> None:
    pass
```

## Return Value

- None

## Function Description

The `startup` function sets the color of all pixels on the LED display to each of the colors in the `colours` dictionary in sequence. The function first sets the color of all pixels to red, waits for one second using the `time.sleep()` function, then sets the color of all pixels to orange, waits for one second, and so on, until the selected colors in the `colours` dictionary have been displayed.

The function uses the `setAllPixelsColour` function to set the color of all pixels to the specified color. The `time.sleep()` function is used to pause the program for one second between each color change.

## Example Usage

```py
# Display all colors in the colours dictionary
startup()
```

In the example above, we call the `startup` function to display all colors in the `colours` dictionary on the LED display.

## Exceptions

- None

## Notes

- The `startup` function assumes that the `setAllPixelsColour` function is defined properly and that it can set the color of all pixels on the LED display. If the `setAllPixelsColour` function is not defined properly or if the LED display is represented differently, the `startup` function should be modified accordingly.

- The `startup` function is intended as a utility function for testing and debugging purposes. It may not be necessary for the final version of the program and can be removed if not needed.

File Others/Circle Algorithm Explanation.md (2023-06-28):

Using
[Bresenham's Circle Algorithm](https://en.m.wikipedia.org/wiki/Midpoint_circle_algorithm), we can compute one octant (one eighth of a circle) and then mirror it four times, flip the x and y values, and mirror it 4 more times to get the whole circle.

## Bresenham's Circle Algorithm

1. Given a radius, $r$, we can store $x=r$ and $y=0$.
2. The $y$ value will be incremented for every point, while the $x$ value will be calculated using a simple comparison.
3. The first point of the circle will be $(x, y)$. Which equates to $(r, 0)$.
4. Increment the $y$ value. Which equates to $(x, y+1)$.
5. If $x^2 + y^2 - r^2 > 0$, then the next point of the circle will be $(x-1, y)$.
6. If $x^2 + y^2 - r^2 \le 0$, then the next point of the circle will be $(x, y)$.
7. Repeating step 4 onwards until $x < y$.
8. Once all the points for the first octant has been computed, all the points should be positive $x$ and $y$ values.
9. Reflect the points in the $x$ only, $y$ only, and $x$ and $y$ axes. This gives the coordinates for three more octants.
10. Flip the $x$ and $y$ values of the originally computed points and repeat step 9 to get the last 4 octants.
11. Display all stored points on the grid, assuming $(0, 0)$ is the center of the grid.

## Implementation

This looks like a simple implementation:
[GeeksForGeeks: Mid-Point Circle Drawing Algorithm](https://www.geeksforgeeks.org/mid-point-circle-drawing-algorithm/amp/)

The explanation is simpler in this example but then starts to get more detailed, which we don't need.

Here's a live demo: [Bresenham Circle Algorithm Demo](http://0x80.pl/articles/bresenham-demo-circle.html)

It looks like it skips a few LEDs, but it would work better with a larger number of LEDs. As the animation will move quickly, you might not be able to see that it skips LEDs, and it might look more natural (more like an actual circular wave).

After getting all the coordinates, we can store it all into an array. Once the circle's coordinates are stored, we can iterate through and update all the LEDs in those positions and then do ```pixels.show()``` to update the LEDs.

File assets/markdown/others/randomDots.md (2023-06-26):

# randomDots function

```py
import time, random

def randomDots(delay):
    pixels[random.randint(0, num_pixels-1)] = (random.randint(0, 255), random.randint(0, 255), random.randint(0, 255))
    pixels.show()
    time.sleep(delay)

while True:
    randomDots(0.1)
```

This function sets a random LED to a random colour. This section of code can be copy and pasted as an experiment.

This function requires the NeoPixel library.

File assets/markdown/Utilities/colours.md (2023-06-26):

# COLOURS dictionary

## Overview

The `COLOURS` dictionary is a collection of key-value pairs representing common colors in the RGB color space. The keys of the dictionary are strings representing the names of the colors, and the values are tuples of three integers representing the RGB values of the colors.

## Dictionary Structure

The `COLOURS` dictionary has the following structure:

```py
COLOURS = {
    "Colour name" : (255, 255, 255)
}
```

## Dictionary Usage

The `COLOURS` dictionary can be used to access RGB color values by their corresponding names. For example, to access the RGB value of the color red, you can use the following code:

```py
red_value = COLOURS["Red"]
```

The value of `red_value` in this case would be the tuple `(255, 0, 0)`, which represents the RGB color red.

## Notes

- The `COLOURS` dictionary is not an exhaustive list of all possible colors in the RGB color space. It is intended as a collection of common colors, and additional colors can be added as needed.

- The keys of the `COLOURS` dictionary are case-sensitive.

- The values of the `COLOURS` dictionary are tuples of three integers representing the RGB values of the colors. Each integer must be between 0 and 255, inclusive.

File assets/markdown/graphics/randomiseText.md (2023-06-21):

# randomiseText function

## Overview

The `randomiseText` function cycles randomly through a list of preset phrases and scrolls them on the screen one by one. The function chooses a phrase at random, scrolls it on the screen, and waits for a specified amount of time before choosing another random phrase.

## Function Signature

```py
def randomiseText(colour: Tuple[int, int, int],
                  delay: float,
                  scroll_delay: float) -> None:
    pass
```

## Parameters

- `colour` = `Tuple[int, int, int]`: A tuple of three integers representing the RGB color values for the text.

- `delay` = `float`: A float value representing the time to wait between each phrase.

- `scroll_delay` = `float`: A float value representing the time to wait between each frame of the scrolling animation.

## Return Value

- `None`: The function does not return any value.

## Function Description

The `randomiseText` function cycles randomly through a list of preset phrases and scrolls them on the screen one by one.

The function starts by defining an array called `all_text` that contains all the preset phrases to be randomly displayed. The function also defines an empty array called `chosen_numbers` to keep track of the phrases that have already been displayed.

The function then enters a loop that continues until all the phrases in `all_text` have been displayed. In each iteration of the loop, the function chooses a random number between 0 and the number of phrases in `all_text`. If the number has not already been chosen, the function calculates the `end_x` position for the current phrase and calls the `scrollText` function to animate the phrase scrolling on the screen. The function then adds the chosen number to the `chosen_numbers` array and waits for a specified amount of time using the `time.sleep` function.

The loop continues until all the phrases in `all_text` have been displayed.

## Example Usage

```py
# Scroll through preset phrases randomly with a delay of 2 seconds between each phrase and 0.1 seconds between each frame of the scrolling animation
randomiseText((255, 255, 255), 2, 0.1)
```

In the example above, we call the `randomiseText` function to cycle randomly through a list of preset phrases and scroll them on the screen.

## Exceptions

- The `randomiseText` function assumes that the `scrollText` function is defined properly and can be used to animate scrolling text on the screen. If this function is not defined properly, the function may not work as expected.

- The `randomiseText` function assumes that the `time.sleep` function is defined properly and can be used to wait for a specified amount of time. If this function is not defined properly, the function may not work as expected.

- The `randomiseText` function assumes that the `colour` parameter is a tuple of three integers representing RGB color values. If the `colour` parameter is not a tuple of three integers, the function may not work as expected.

- The `randomiseText` function assumes that the `delay` parameter is a float value representing the time to wait between each phrase. If the `delay` parameter is not a float value, the function may not work as expected.

- The `randomiseText` function assumes that the `scroll_delay` parameter is a float value representing the time to wait between each frame of the scrolling animation. If the `scroll_delay` parameter is not a float value, the function may not work as expected.

- The `randomiseText` function may not work as expected if the preset phrases in `all_text` are not defined properly or if the phrases are too large to fit on the screen. In this case, the text may be cut off or may not be visible.

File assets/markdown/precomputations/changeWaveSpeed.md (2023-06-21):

# changeWaveSpeed function

## Overview

The `changeWaveSpeed` function takes a wave array that includes color information and changes its speed based on the given ratio. This can be used to slow down or speed up the wave animation. If the ratio is less than 1, the function duplicates each tick in the wave array to slow down the wave. If the ratio is greater than 1, the function removes ticks from the wave array to speed up the wave.

## Function Signature

```py
def changeWaveSpeed(wave_array: List[List[List[int]]], ratio: float = 1) -> List[List[List[int]]]:
    pass
```

## Parameters

- `wave_array` = `List[List[List[int]]]`: A three-dimensional list representing the LED coordinates and color values for each tick in the wave animation. Each top-level item in the list represents a tick, and each item in the second-level list represents an LED that should be illuminated for that tick. The third-level list contains the x and y coordinates of the LED, as well as its RGB color values.

- `ratio` = `float`: A float value representing the ratio by which the wave speed should be changed. If the ratio is less than 1, the wave speed will be slowed down. If the ratio is greater than 1, the wave speed will be sped up. The default value is 1, which means that the wave speed will not be changed.

## Return Value

- `List[List[List[int]]]`: A three-dimensional list representing the new wave array with the changed speed. Each top-level item in the list represents a tick, and each item in the second-level list represents an LED that should be illuminated for that tick. The third-level list contains the x and y coordinates of the LED, as well as its RGB color values.

## Function Description

The `changeWaveSpeed` function takes a wave array that includes color information and changes its speed based on the given ratio.

If the ratio is less than 0, the function raises a `ValueError` with a message indicating that the ratio is out of bounds.

If the ratio is less than 1, the function duplicates each tick in the wave array by a number of times equal to the inverse of the ratio. For example, if the ratio is 0.5, each tick in the wave array will be duplicated twice. The duplicated ticks are added to a new wave array.

If the ratio is greater than 1, the function removes ticks from the wave array by a number of times equal to the ratio minus 1. For example, if the ratio is 2, every other tick in the wave array will be removed. The remaining ticks are added to a new wave array.

The function returns the new wave array with the changed speed.

## Example Usage

```py
# Change wave speed by slowing it down
new_wave_array = changeWaveSpeed(wave_array, 0.5)

# Change wave speed by speeding it up
new_wave_array = changeWaveSpeed(wave_array, 2.0)
```

In the examples above, we call the `changeWaveSpeed` function to change the speed of a wave array by slowing it down or speeding it up.

## Exceptions

- The `changeWaveSpeed` function assumes that the LED coordinates in the wave array are represented as a list of two integers. If the LED coordinates are represented differently, the function should be modified accordingly.

- The `changeWaveSpeed` function assumes that the wave array has at least one tick. If the wave array is empty, the function may raise an error.

- The `changeWaveSpeed` function assumes that the ratio is a float value. If the ratio is represented differently, the function should be modified accordingly.

- The `changeWaveSpeed` function assumes that the ratio is not negative. If the ratio is negative, the function raises a `ValueError` with a message indicating that the ratio is out of bounds.

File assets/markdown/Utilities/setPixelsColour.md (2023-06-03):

# setPixelsColour function

## Overview

The `setPixelsColour` function takes an RGB color as a tuple of three integers, and sets all pixels in a specified range to the specified color. This function is useful for applications that require setting the color of a specific range of pixels on the LED display.

## Function Signature

```py
def setPixelsColour(colour: Tuple[int, int, int],
                    pixel_index_start: int,
                    pixel_index_end: Optional[int] = None) -> None:
    pass
```

## Parameters

- `colour` = `(Tuple[int, int, int])`: A tuple of three integers representing the RGB color. The first integer represents the red component, the second integer represents the green component, and the third integer represents the blue component. Each component must be an integer between 0 and 255, inclusive.

- `pixel_index_start` = `(int)`: An integer representing the index of the first pixel to set to the specified color. This must be an integer between 0 and the total number of pixels minus 1, inclusive.

- `pixel_index_end` = `(int)`: An **optional** integer representing the index of the last pixel to set to the specified color. If this parameter is not provided, only the pixel at `pixel_index_start` will be set to the specified color.

## Return Value

- None

## Function Description

The `setPixelsColour` function takes an RGB color as a tuple of three integers, `colour`, the index of the first pixel to set to the specified color, `pixel_index_start`, and an optional index of the last pixel to set to the specified color, `pixel_index_end`. The function sets all pixels in the specified range to the specified color.

If `pixel_index_end` is not provided, the function sets the color of a single pixel at the index `pixel_index_start` to the specified color. Otherwise, the function uses a loop to set the color of all pixels between `pixel_index_start` and `pixel_index_end`, inclusive, to the specified color.

## Example Usage

```py
# Set pixels 5-7 to red
setPixelsColour((255, 0, 0), 5, 7)
```

In the example above, we call the `setPixelsColour` function with the tuple `(255, 0, 0)` to set the color to red, and `pixel_index_start` equal to 5 and `pixel_index_end` equal to 7 to set the color of pixels 5, 6, and 7 to red.

```py
# Set pixel 3 to green
setPixelsColour((0, 255, 0), 3)
```

In the example above, we call the `setPixelsColour` function with`pixel_index_start` equal to 3 and no `pixel_index_end` specified, so the function sets the color of only pixel 3 to green.

## Exceptions

- `TypeError`: If the `colour` parameter is not a tuple of three integers, or if `pixel_index_start` or `pixel_index_end` (if provided) is not an integer, a `TypeError` is raised.

- `ValueError`: If any of the color components in the `colour` tuple is not an integer between 0 and 255, inclusive, or if `pixel_index_start` or `pixel_index_end` (if provided) is not within the appropriate range for the LED display, a `ValueError` is raised.

## Notes

- The `setPixelsColour` function assumes that the LED display is represented by the `pixels` object and that it has the ability to set individual pixel colors. If the LED display is represented differently or if the display methods have different names, the function should be modified accordingly.

- The `setPixelsColour` function does not perform any error checking beyond checking that the input parameters are of the correct type and within the appropriate range. It is the responsibility of the calling code to ensure that the input values are valid.

- The coordinate system starts from the bottom left and the first LED is at position $(0, 0)$.

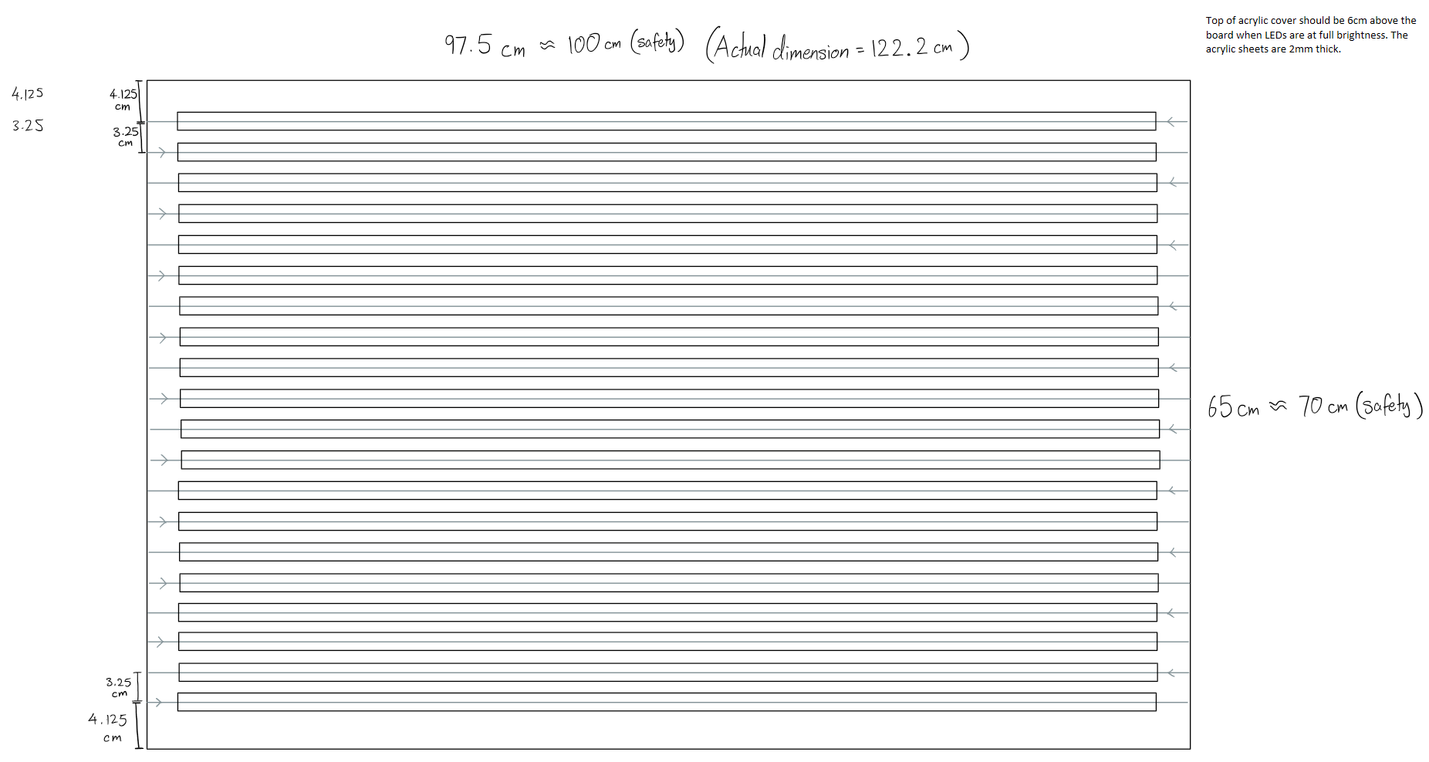
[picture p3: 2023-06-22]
assets/img/thumbnails/v2/designs/designs-7.png

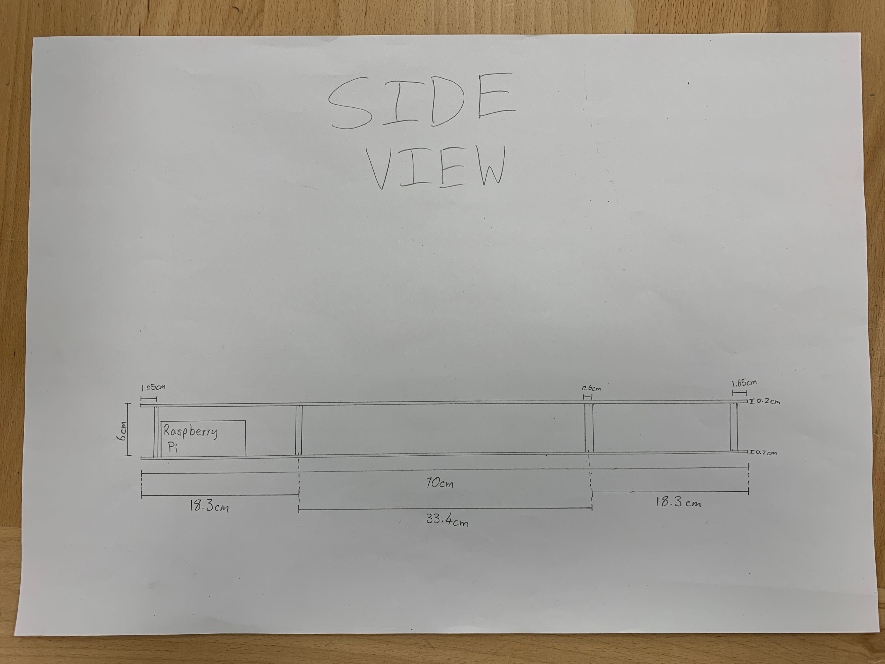
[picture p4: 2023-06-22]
assets/img/fullsize/v2/designs/designs-4.jpg

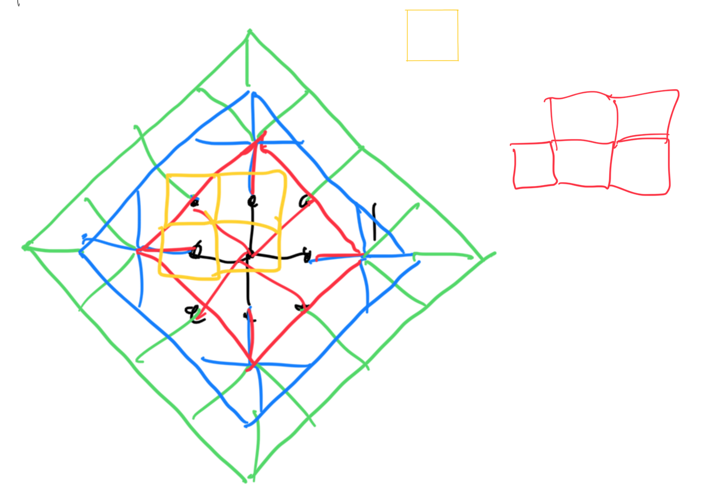
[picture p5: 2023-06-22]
assets/img/fullsize/v2/designs/designs-5.png

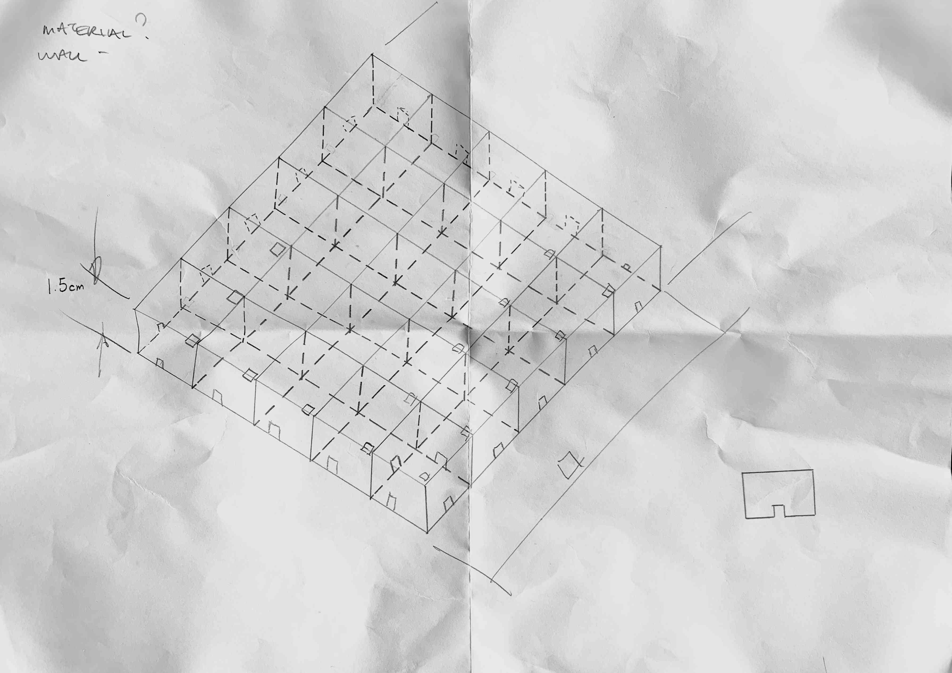
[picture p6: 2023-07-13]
assets/img/thumbnails/v2/designs/designs-1.jpg

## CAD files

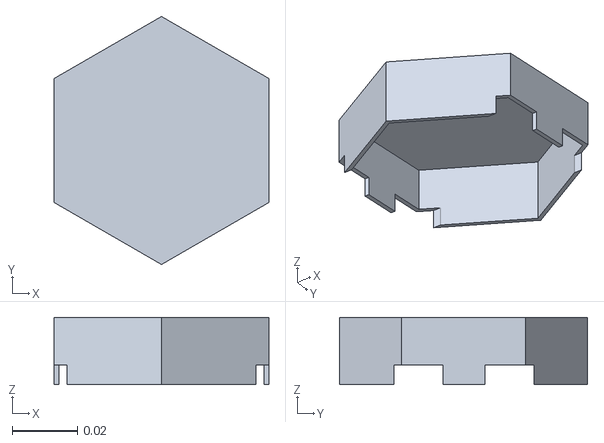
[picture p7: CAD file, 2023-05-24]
Others/3D Models/LED Lights Shell v3.stl
0.0657 x 0.0758 x 0.0206

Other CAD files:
Others/3D Models/LED Lights Shell v2.stl
Others/3D Models/LED Lights 3D Model.blend
Others/3D Models/LED Lights Shell Demo.blend
Others/3D Models/LED Lights Shell v3.blend

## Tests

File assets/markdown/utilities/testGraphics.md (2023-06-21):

# testGraphics function

## Overview

The `testGraphics` function draws various shapes and text on the screen to test the graphics capabilities of the display. The function draws a line, straight line, rectangle, circle, and scrolling text on the screen.

## Function Signature

```py
def testGraphics(delay: float = 1.0) -> None:
    pass
```

## Parameters

- `delay` = `float`: A float value representing the time to wait between each shape or text being drawn on the screen. The default value is 1 second.

## Return Value

- `None`: The function does not return any value.

## Function Description

The `testGraphics` function draws various shapes and text on the screen to test the graphics capabilities of the display.

The function starts by calling the `drawLine` function to draw a diagonal line from $(0, 0)$ to $(3, 2)$ with the color green. The function then calls the `drawStraightLine` function twice to draw a vertical line and a horizontal line with the color blue. The function then calls the `drawRect` function twice to draw a rectangle with the color red and an outlined rectangle with the color orange. Finally, the function calls the `drawCircle` function to draw a circle with the color green.

After drawing all shapes, the function waits for a specified amount of time using the `time.sleep` function and then clears the screen by calling the `setAllPixelsColour` function with the color black. The function then calls the `scrollText` function to scroll the text "Text" on the screen with the color red. The function waits for a specified amount of time between each frame of the scrolling animation and then clears the screen again by calling the `setAllPixelsColour` function with the color black.

## Example Usage

```py
# Test graphics capabilities of the display
testGraphics(0.5)
```

In the example above, we call the `testGraphics` function to draw various shapes and text on the screen and test the graphics capabilities of the display.

## Exceptions

- The `testGraphics` function assumes that the `drawLine`, `drawStraightLine`, `drawRect`, `drawCircle`, `scrollText`, and `setAllPixelsColour` functions are defined properly and can be used to draw on the screen and clear the screen. If these functions are not defined properly, the function may not work as expected.

- The `testGraphics` function assumes that the `delay` parameter is a float value representing the time to wait between each shape or text being drawn on the screen. If the `delay` parameter is not a float value, the function may not work as expected.

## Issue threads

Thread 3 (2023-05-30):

Use ultrasonic sensors to detect 2d position of an object

WhenLifeHandsYouLemons, 2023-05-30:
To do:
- [x] Connect sensors to the RPi
- [x] Get a demo of one sensor working
- [x] Get 2 sensors working simultaneously
- [x] Create a graph visualisation to find any dead-zones
- [x] Create code to combine multiple sensors' data on each axis into a single value for each axis.
- [ ] Wire 5 sensors and test the field of views
- [x] Clean up data as it's coming in to then pass to the wave functions to create waves
- [x] Remap physical positions to LED positions

WhenLifeHandsYouLemons, 2023-06-01:
Can also use multiple ultrasonic sensors and get the shortest distance from each side.

WhenLifeHandsYouLemons, 2023-06-02:
Use 3 ultrasonic sensors on the long edge and 2 on the short edge so that it can cover the most area of the board. 5 sensors can be connected to the RPi at most.

WhenLifeHandsYouLemons, 2023-06-07:
Using 1 on the short edge and 2 on the long edge fills most of the board with the minimal number of ultrasonic sensors required.

WhenLifeHandsYouLemons, 2023-06-08:
```
.68, 65.68, 65.68, 65.68, 65.68, 65.68, 65.68, 65.68, 65.68, 65.68, 65.68, 65.68, 65.68, 65.68, 65.68, 65.68, 65.68, 65.68, 65.68, 65.68, 65.68, 65.68, 65.68, 65.68, 65.68, 65.68, 65.68, 65.68, 65.68, 65.68, 65.68, 65.68, 65.68, 65.68, 65.68, 65.68, 65.68, 65.68, 65.68, 65.68, 65.68, 65.68, 65.68, 65.68, 65.68, 65.68, 65.68, 65.68, 65.68, 65.68, 65.68, 65.68, 65.68, 65.68, 65.68, 65.68, 65.68, 65.68, 65.68, 65.68, 65.68, 65.68, 65.68, 65.68, 65.68, 65.68, 65.68, 65.68, 65.68, 65.68, 65.68, 65.68, 65.68, 65.68, 65.68, 65.68, 65.68, 65.68, 65.68, 65.68, 65.68, 65.68, 65.68, 65.68, 65.68, 65.68, 65.68, 65.68, 65.68, 65.68, 65.68, 65.68, 65.68, 65.68, 65.68, 65.68, 65.68, 65.68, 65.68, 65.68, 65.68, 65.68, 65.68, 65.68, 65.68, 65.68, 65.68, 65.68, 65.68, 65.68, 65.68, 65.68, 65.68, 65.68, 65.68, 65.68, 65.68, 65.68, 65.68, 65.68, 65.68, 65.68, 65.68, 65.68, 65.68, 65.68, 65.68, 65.68, 65.68, 65.68, 65.68, 65.68, 65.68, 65.68, 65.68, 65.68, 65.68, 65.68, 65.68, 65.68, 65.68, 65.68, 65.68, 65.68, 65.68, 65.68, 65.68, 65.68, 65.68, 65.68, 65.68, 65.68, 65.68, 65.68, 65.68, 65.68, 65.68, 65.68, 65.68, 65.68, 65.68, 65.68, 65.68, 65.68, 65.68, 65.68, 65.68, 65.68, 65.68, 65.68, 65.68, 65.68, 65.68, 65.68, 65.68, 65.68, 65.68, 65.68, 65.68, 65.68, 65.68, 65.68, 65.68, 65.68, 65.68, 65.68, 65.68, 65.68, 65.68, 65.68, 65.68, 65.68, 65.68, 65.68, 65.68, 65.0, 65.0, 65.0, 65.0, 65.0, 65.0, 65.0, 65.0, 65.0, 65.0, 65.0, 65.0, 65.0, 65.0, 65.0, 65.0, 65.0, 65.0, 65.0, 65.0, 65.0, 65.0, 65.0, 65.0, 65.0, 65.0, 65.0, 65.0, 65.0, 65.0, 65.0, 65.0, 65.0, 65.0, 65.0, 65.0, 65.0, 65.0, 65.0, 65.0, 65.0, 65.0, 65.0, 65.0, 65.0, 65.0, 65.0, 65.0, 65.0, 65.0, 65.0, 65.0, 65.0, 65.0, 65.0, 65.0, 65.0, 65.0, 65.0, 65.0, 65.0, 65.0, 65.0, 65.0, 65.0, 65.0, 65.0, 65.0, 65.0, 65.0, 65.0, 65.0, 65.0, 65.0, 65.0, 65.0, 65.0, 65.0, 65.0, 65.0, 65.0, 65.0, 65.0, 65.0, 65.0, 65.0, 65.0, 65.0, 65.0, 65.0, 65.0, 65.0, 65.0, 65.0, 65.0, 65.0, 65.0, 65.0, 65.0, 65.0, 65.0, 65.0, 65.0, 65.0, 65.0, 65.0, 65.0, 65.0, 65.0, 65.0, 65.0, 65.0, 65.0, 65.0, 65.0, 65.0, 65.0, 65.0, 65.0, 65.0, 65.0, 65.0, 65.0, 65.0, 65.0, 65.0, 65.0, 65.0, 65.0, 65.0, 65.0, 65.0, 65.0, 65.0, 65.0, 65.0, 65.0, 65.0, 65.0, 65.0, 65.0, 65.0, 65.0, 65.0, 65.0, 65.0, 65.0, 65.0, 65.0, 65.0, 65.0, 65.0, 65.0, 65.0, 65.0, 65.0, 65.0, 65.0, 65.0, 65.0, 65.0, 65.0, 65.0, 65.0, 65.0, 65.0, 65.0, 65.0, 65.0, 65.0, 65.0, 65.0, 65.0, 65.0, 65.0, 65.0, 65.0, 65.0, 65.0, 65.0, 65.0, 65.0, 65.0, 65.0, 65.0, 65.0, 65.0, 65.0, 65.0, 65.0, 65.0, 65.0, 65.0, 65.0, 65.0, 65.0, 65.0, 65.0, 65.0, 65.0, 65.0, 65.0, 65.0, 65.0, 65.0, 65.0, 65.0, 65.0, 65.0, 65.0, 65.0, 65.0, 65.0, 65.0, 65.0, 65.0, 65.0, 65.0, 65.0, 65.0, 65.0, 65.0, 65.0, 65.0, 65.0, 65.0, 65.0, 65.0, 65.0, 65.0, 65.0, 65.0, 65.0, 65.0, 65.0, 65.0, 65.0, 65.0, 65.0, 65.0, 65.0, 65.0, 65.0, 65.0, 65.0, 65.0, 65.0, 65.0, 65.0, 65.0, 65.0, 65.0, 65.0, 65.0, 65.0, 65.0, 65.0, 65.0, 65.0, 65.0, 65.0, 65.0, 65.0, 65.0, 65.0, 65.0, 65.0, 65.0, 65.0, 65.0, 65.0, 65.0, 65.0, 65.0, 65.0, 65.0, 65.0, 65.0, 65.0, 65.0, 65.0, 65.0, 65.0, 65.0, 65.0, 65.0, 65.0, 65.0, 65.0, 65.0, 65.0, 65.0, 65.0, 65.0, 65.0, 65.0, 65.0, 65.0, 65.0, 65.0, 65.0, 65.0, 65.0, 65.0, 65.0, 65.0, 65.0, 65.0, 65.0, 65.0, 65.0, 65.0, 65.0, 65.0, 65.0, 65.0, 65.0, 65.0, 65.0, 65.0, 65.0, 65.0, 65.0, 65.0, 65.0, 65.0, 65.0, 65.0, 65.0, 65.0, 65.0, 65.0, 65.0, 65.0, 65.0, 65.0, 65.0, 65.0, 65.0, 65.0, 65.0, 65.0, 65.0, 65.0, 65.0, 65.0, 65.0, 65.0, 65.0, 65.0, 65.0, 65.0, 65.0, 65.0, 65.0, 65.0, 65.0, 65.0, 65.0, 65.0, 65.0, 65.0, 65.0, 65.0, 65.0, 65.0, 65.0, 65.0, 65.0, 65.0, 65.0, 65.0, 65.0, 65.0, 65.0, 65.0, 65.0, 65.0, 65.0, 65.0, 65.0, 65.0, 65.0, 65.0, 65.0, 65.0, 65.0, 65.0, 65.0, 65.0, 65.0, 65.0, 65.0, 65.0, 65.0, 65.0, 65.0, 65.0, 65.0, 65.0, 65.0, 65.0, 65.0, 65.0, 65.0, 65.0, 65.0, 65.0, 65.0, 65.0, 65.0, 65.0, 65.0, 65.0, 65.0, 65.0, 65.0, 65.0, 65.0, 65.0, 65.0, 65.0, 65.0, 65.0, 65.0, 65.0, 65.0, 65.0, 65.0, 65.0, 65.0, 65.0, 65.0, 65.0, 65.0, 65.0, 65.0, 65.0, 65.0, 65.0, 65.0, 65.0, 65.0, 65.0, 65.0, 65.0, 65.0, 65.0, 65.0, 65.0, 65.0, 65.0, 65.0, 65.0, 65.0, 65.0, 65.0, 65.0, 65.0, 65.0, 65.0, 65.0, 65.0, 65.0, 65.0, 65.0, 65.0, 65.0, 65.0, 65.0, 65.0, 65.0, 65.0, 65.0, 65.0, 65.0, 65.0, 65.0, 65.0, 65.0, 65.0, 65.0, 65.0, 65.0, 65.0, 65.0, 65.0, 65.0, 65.0, 65.0, 65.0, 65.0, 64.98, 64.98, 64.98, 64.98, 64.98, 64.98, 64.98, 64.98, 64.98, 64.98, 64.98, 64.98, 64.98, 64.98, 64.98, 64.98, 64.98, 64.98, 64.98, 64.98, 64.98, 64.98, 64.98, 64.98, 64.98, 64.98, 64.98, 64.98, 64.98, 64.98, 64.98, 64.98, 64.98, 64.98, 64.98, 64.98, 64.98, 64.98, 64.98, 64.98, 64.98, 64.98, 64.98, 64.98, 64.98, 64.98, 64.98, 64.98, 64.98, 64.98, 64.98, 64.98, 64.98, 64.98, 64.98, 64.98, 64.98, 64.98, 64.98, 64.98, 64.98, 64.98, 64.98, 64.98, 64.98, 64.98, 64.98, 64.98, 64.98, 64.98, 64.98, 64.98, 64.98, 64.98, 64.98, 64.98, 64.98, 64.98, 64.98, 64.98, 64.98, 64.98, 64.98, 64.98, 64.98, 64.98, 64.98, 64.98, 64.98, 64.98, 64.98, 64.98, 64.98, 64.98, 64.98, 64.98, 64.98, 64.98, 64.98, 64.98, 64.98, 64.98, 64.98, 64.98, 64.98, 64.98, 64.98, 64.98, 64.98, 64.98, 64.98, 64.98, 64.98, 64.98, 64.98, 64.98, 64.98, 64.98, 64.98, 64.98, 64.98, 64.98, 64.98, 64.98, 64.98, 64.98, 64.98, 64.98, 64.98, 64.98, 64.98, 64.98, 64.98, 64.98, 64.98, 64.98, 64.98, 64.98, 64.98, 64.98, 64.98, 64.98, 64.98, 64.98, 64.98, 64.98, 64.98, 64.98, 64.98, 64.98, 64.98, 64.98, 64.98, 64.98, 64.98, 64.98, 64.98, 64.98, 64.98, 64.98, 64.98, 64.98, 64.98, 64.98, 64.98, 64.98, 64.98, 64.98, 64.98, 64.98, 64.98, 64.98, 64.98, 64.98, 64.98, 64.98, 64.98, 64.98, 64.98, 64.98, 64.98, 64.98, 64.98, 64.98, 64.98, 64.98, 64.98, 64.98, 64.98, 64.98, 64.98, 64.98, 64.98, 64.98, 64.98, 64.98, 64.98, 64.98, 64.98, 64.98, 64.98, 64.98, 64.98, 64.98, 64.98, 64.98, 64.98, 64.98, 64.98, 64.98, 64.98, 64.98, 64.98, 64.98, 64.98, 64.98, 64.98, 64.98, 64.98, 64.98, 64.98, 64.98, 64.98, 64.98, 64.98, 64.98, 64.98, 64.98, 64.98, 64.98, 64.98, 64.98, 64.98, 64.98, 64.98, 64.98, 64.98, 64.98, 64.98, 64.98, 64.98, 64.98, 64.98, 64.98, 64.98, 64.98, 64.98, 64.98, 64.98, 64.98, 64.98, 64.98, 64.98, 64.98, 64.98, 64.98, 64.98, 64.98, 64.98, 64.98, 64.98, 64.98, 64.98, 64.98, 64.98, 64.98, 64.98, 64.98, 64.98, 64.98, 64.98, 64.98, 64.98, 64.98, 64.98, 64.98, 64.98, 64.98, 64.98, 64.98, 64.98, 64.98, 64.98, 64.98, 64.98, 64.98, 64.98, 64.98, 64.98, 64.98, 64.98, 64.98, 64.98, 64.98, 64.98, 64.98, 64.98, 64.98, 64.98, 64.98, 64.98, 64.98, 64.98, 64.98, 64.98, 64.98, 64.98, 64.98, 64.98, 64.98, 64.98, 64.98, 64.98, 64.98, 64.98, 64.98, 64.98, 64.98, 64.98, 64.98, 64.98, 64.98, 64.98, 64.98, 64.98, 64.98, 64.98, 64.98, 64.98, 64.98, 64.98, 64.98, 64.98, 64.98, 64.98, 64.98, 64.98, 64.98, 64.98, 64.98, 64.98, 64.98, 64.98, 64.98, 64.98, 64.98, 64.98, 64.98, 64.98, 64.98, 64.98, 64.98, 64.98, 64.98, 64.98, 64.98, 64.98, 64.98, 64.98, 64.98, 64.98, 64.98, 64.98, 64.98, 64.98, 64.98, 64.98, 64.98, 64.98, 64.98, 64.98, 64.98, 64.98, 64.98, 64.98, 64.98, 64.98, 64.98, 64.98, 64.98, 64.98, 64.98, 64.98, 64.98, 64.98, 64.98, 64.98, 64.98, 64.98, 64.98, 64.98, 64.98, 64.98, 64.98, 64.98, 64.98, 64.98, 64.98, 64.98, 64.98, 64.98, 64.98, 64.98, 64.98, 64.98, 64.98, 64.98, 64.98, 64.98, 64.98, 64.98, 64.98, 64.98, 64.98, 64.98, 64.98, 64.98, 64.98, 64.98, 64.98, 64.98, 64.98, 64.98, 64.98, 64.98, 64.98, 64.98, 64.98, 64.98, 64.98, 64.98, 64.98, 64.98, 64.98, 64.98, 64.98, 64.98, 64.98, 64.98, 64.98, 64.98, 64.98, 64.98, 64.98, 64.98, 64.98, 64.98, 64.98, 64.98, 64.98, 64.98, 64.98, 64.98, 64.98, 64.98, 64.98, 64.98, 64.98, 64.98, 64.98, 64.98, 64.98, 64.98, 64.98, 64.98, 64.98, 64.98, 64.98, 64.98, 64.98, 64.98, 64.98, 64.98, 64.98, 64.98, 64.98, 64.98, 64.98, 64.98, 64.98, 64.98, 64.98, 64.98, 64.98, 64.98, 64.98, 64.98, 64.98, 64.98, 64.98, 64.98, 64.98, 64.98, 64.98, 64.98, 64.98, 64.98, 64.98, 64.98, 64.98, 64.98, 64.98, 64.98, 64.98, 64.98, 64.98, 64.98, 64.98, 64.98, 64.98, 64.98, 64.98, 64.98, 64.98, 64.98, 64.98, 64.98, 64.98, 64.98, 64.98, 64.98, 64.98, 64.98, 64.98, 64.98, 64.98, 64.98, 64.98, 64.98, 64.98, 64.98, 64.98, 64.98, 64.98, 64.98, 64.98, 64.98, 64.98, 64.98, 64.98, 64.98, 64.98, 64.98, 64.98, 64.98, 64.98, 64.98, 64.98, 64.98, 64.98, 64.98, 64.98, 64.98, 64.98, 64.98, 64.98, 64.98, 64.98, 64.98, 64.98, 64.98, 64.98, 64.98, 64.98, 64.98, 64.98, 64.98, 64.98, 64.98, 64.98, 64.98, 64.98, 64.98, 64.98, 64.98, 64.98, 64.98, 64.98, 64.98, 64.98, 64.98, 64.98, 64.98, 64.98, 64.98, 64.98, 64.98, 64.98, 64.98, 64.98, 64.98, 64.98, 64.98, 64.98, 64.98, 64.98, 64.98, 64.98, 64.98, 64.98, 64.98, 64.98, 64.98, 64.98, 64.98, 64.98, 64.98, 64.98, 64.98, 64.98, 64.98, 64.98, 64.98, 64.98, 64.98, 64.98, 64.98, 64.98, 64.98, 64.98, 64.98, 64.98, 64.98, 64.98, 64.98, 64.98, 64.98, 64.98, 64.98, 64.98, 64.98, 64.98, 64.98, 64.98, 64.98, 64.98, 64.98, 64.98, 64.98, 64.98, 64.98, 64.98, 64.98, 64.98, 64.98, 64.98, 64.98, 64.98, 64.98, 64.98, 64.98, 64.98, 64.98, 64.98, 64.98, 64.98, 64.98, 64.98, 64.98, 64.98, 64.98, 64.98, 64.98, 64.98, 64.98, 64.98, 64.98, 64.98, 64.98, 64.98, 64.98, 64.98, 64.98, 64.98, 64.98, 64.98, 64.98, 64.98, 64.98, 64.98, 64.98, 64.98, 64.98, 64.98, 64.98, 64.98, 64.98, 64.98, 64.98, 64.98, 64.98, 64.98, 64.98, 64.98, 64.98, 64.98, 64.98, 64.98, 64.98, 64.98, 64.98, 64.98, 64.98, 64.98, 64.98, 64.98, 64.98, 64.98, 64.98, 64.98, 64.98, 64.98, 64.98, 64.98, 64.98, 64.98, 64.98, 64.98, 64.98, 64.98, 64.98, 64.98, 64.98, 64.98, 64.98, 64.98, 64.98, 64.98, 64.98, 64.98, 64.98, 64.98, 64.98, 64.98, 64.98, 64.98, 64.98, 64.98, 64.98, 64.98, 64.98, 64.98, 64.98, 64.98, 64.98, 64.98, 64.98, 64.98, 64.98, 64.98, 64.98, 64.98, 64.98, 64.98, 64.98, 64.98, 64.98, 64.98, 64.98, 64.98, 64.98, 64.98, 64.98, 64.98, 64.98, 64.98, 64.98, 64.98, 64.98, 64.98, 64.98, 64.98, 64.98, 64.98, 64.98, 64.98, 64.98, 64.98, 64.98, 64.98, 64.98, 64.98, 64.98, 64.98, 64.98, 64.98, 64.98, 64.98, 64.98, 64.98, 64.98, 64.98, 64.98, 64.98, 64.98, 64.98, 64.98, 64.98, 64.98, 64.98, 64.98, 64.98, 64.98, 64.98, 64.98, 64.98, 64.98, 64.98, 64.98, 64.98, 64.98, 64.98, 64.98, 64.98, 64.98, 64.98, 64.98, 64.98, 64.98, 64.98, 64.98, 64.98, 64.98, 64.98, 64.98, 64.98, 64.98, 64.98, 64.98, 64.98, 64.98, 64.98, 64.98, 64.98, 64.98, 64.98, 64.98, 64.98, 64.98, 64.98, 64.98, 64.98, 64.98, 64.98, 64.98, 64.98, 64.98, 64.98, 64.98, 64.98, 64.98, 64.98, 64.98, 64.98, 64.98, 64.98, 64.98, 64.98, 64.98, 64.98, 64.98, 64.98, 64.98, 64.98, 64.98, 64.98, 64.98, 64.98, 64.98, 64.98, 64.98, 64.98, 64.98, 64.98, 64.98, 64.98, 64.98, 64.98, 64.98, 64.98, 64.98, 64.98, 64.98, 64.98, 64.98, 64.98, 64.98, 64.98, 64.98, 64.98, 64.98, 64.98, 64.98, 64.98, 64.98, 64.98, 64.98, 64.98, 64.98, 64.98, 64.98, 64.98, 64.98, 64.98, 64.98, 64.98, 64.98, 64.98, 64.98, 64.98, 64.98, 64.98, 64.98, 64.98, 64.98, 64.98, 64.98, 64.98, 64.98, 64.98, 64.98, 64.98, 64.98, 64.98, 64.98, 64.98, 64.98, 64.98, 64.98, 64.98, 64.98, 64.98, 64.98, 64.98, 64.98, 64.98, 64.98, 64.98, 64.98, 64.98, 64.98, 64.98,
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

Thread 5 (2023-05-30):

Overheating Issue

WhenLifeHandsYouLemons, 2023-05-30:
To fix the overheating issue, we used 4 separate cables and didn't join them into one wire as that was too much power and melted the plastic connectors. This reduced the power draw for each plug to 1/4 of the previous amount and now it takes around 10 minutes of all the LEDs being on at full brightness for it to become concerningly warm.

WhenLifeHandsYouLemons, 2023-06-01:
Fixed power draw and overheating issue. Can implement the ultrasonic sensor method.

Closed 2023-06-01.

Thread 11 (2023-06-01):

Fix precomputeWave function

WhenLifeHandsYouLemons, 2023-06-01:
Using a direction of 0 or 3 works correctly, the other two don't work as intended.

WhenLifeHandsYouLemons, 2023-06-07:
Error log:
```
Traceback (most recent call last):
  File "/home/pi/Desktop/LED-Light-Wall-main/rpi_code.py", line 664, in <module>
    displayWave(merged_test_waves, 0.3)
  File "/home/pi/Desktop/LED-Light-Wall-main/rpi_code.py", line 462, in displayWave
    setPixelsColour(LED[2], getLED(LED[0], LED[1]))
  File "/home/pi/Desktop/LED-Light-Wall-main/rpi_code.py", line 71, in setPixelsColour
    pixels[pixel_index_start] = colour
  File "/usr/local/lib/python3.7/dist-packages/adafruit_pixelbuf.py", line 309, in __setitem__
    self._set_item(index, r, g, b, w)
  File "/usr/local/lib/python3.7/dist-packages/adafruit_pixelbuf.py", line 273, in _set_item
    raise IndexError
IndexError
```

WhenLifeHandsYouLemons, 2023-06-07:
Doing this:
```py
precomputeWave(2, 15)
```

Also causes it to not display as intended. However, it doesn't throw an error and continues running.

Closed 2023-06-08.

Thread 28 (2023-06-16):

Glue wooden pieces for sensors

WhenLifeHandsYouLemons, 2023-06-16:
Need to glue pieces of wood for the ultrasonic sensors.

WhenLifeHandsYouLemons, 2023-06-23:
Very similar to issue #1, but glueing it instead of drilling it and we're using it to hold ultrasonic sensors rather than covering wires.

Closed 2023-06-23.

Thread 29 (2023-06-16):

Fix RPi on to board

WhenLifeHandsYouLemons, 2023-06-16:
Need to drill holes into the board base to screw the RPi into place.

Closed 2023-06-23.

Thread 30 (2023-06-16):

Fix ultrasonic sensors to board

WhenLifeHandsYouLemons, 2023-06-16:
Need to drill holes into the wooden pieces to screw the ultrasonic sensors into place.

Can be completed after this: #28

Closed 2023-06-23.

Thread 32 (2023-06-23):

Mount board to the wall

WhenLifeHandsYouLemons, 2023-06-23:
Need to ask Mr B about how we can mount it

WhenLifeHandsYouLemons, 2023-06-26:
We just send a summary email to Mr B about what we need to do (mount and power it).

Also linked to this issue: #

Closed 2023-06-26.

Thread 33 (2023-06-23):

Figure out how to power the board outside

WhenLifeHandsYouLemons, 2023-06-23:
Ask Mr B about how to fix the power supply outside.

WhenLifeHandsYouLemons, 2023-06-26:
Look at this issue (#32) for what we need to do still.

Closed 2023-06-26.

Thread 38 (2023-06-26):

Send summary email

WhenLifeHandsYouLemons, 2023-06-26:
Need to send a summary email to Mr B about what we've done so far, what needs to be done and - if we know - how.

WhenLifeHandsYouLemons, 2023-07-28:
Things to include in the email:
1. How to power the board and Pi from the outside
2. Drawing of where the board is supposed to hang
3. Fix the sides of the board (change it from paper to a different material)
4. How to update the code on the Pi and run it
5. Fix the `displayImage()` function (not sure how to fix it as we can't debug it without the board)
6. How to hang the board on the wall outside
7. Include link to stickers google docs

Closed 2023-08-07.

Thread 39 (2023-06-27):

Fix ultrasonic sensing code

WhenLifeHandsYouLemons, 2023-06-27:

Closed 2023-06-27.

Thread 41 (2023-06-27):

Change polling frequency

WhenLifeHandsYouLemons, 2023-06-27:
Make the code poll the ultrasonic sensors every time it updates the board for the next tick so that it can be stopped mid-sequence and start the ultrasonic tracking. Once the tracking if finished, it can continue the sequence where it left off.

Closed 2023-06-28.

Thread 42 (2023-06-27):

Make final display code

WhenLifeHandsYouLemons, 2023-06-27:
Create the code that will run randomisePatterns endlessly for the final display code.

WhenLifeHandsYouLemons, 2023-06-28:
Pattern 3 in randomisePatterns hangs and runs forever.

WhenLifeHandsYouLemons, 2023-06-30:
This section of code seems to run forever as well. Not sure why that happens or what exact loop is running forever, but here's the trace when I stopped the program:

```txt
Calculating waves...
Total patterns: 3
Getting pattern 0, chosen 4
Got pattern 0
Getting pattern 1, chosen 4
Got pattern 1
Getting pattern 2, chosen 4
Traceback (most recent call last):
  File ".../LED-Light-Wall/Pygame Testing/pygame_main.py", line 31, in <module>
    merged, non_merged = randomisePatterns()
  File "...\LED-Light-Wall\Pygame Testing\pygame_precomputations.py", line 727, in randomisePatterns
    dx = math.fabs(x - ii[0])
KeyboardInterrupt
^C
```

WhenLifeHandsYouLemons, 2023-06-30:
Fixed the issue of the ZeroDivisonError by adding a small check to see whether the `precomputeLines` function returns an array with one tick. If it does, then it changes the end positions and runs it again until it isn't a length of $1$.

---

Fixed the other issue of the infinitely running loop. It happened because the minimum separation between waves had to be 4 LEDs in both x and y directions.

It happens in this specific case, where:
- It chooses $3$ patterns to be displayed
- The first two patterns are both precomputeLines so that there are a total of $4$ LED positions in the `log` array
- The start and end positions of the lines just so happen to be chosen such that there is no other possible position to choose for the third pattern that is at least $4$ LEDs away from every other chosen position in the y direction

In that one case, the program goes into an endless loop as it tries to find a new position for the third pattern that fulfills all the requirements which isn't possible anymore.

Decreasing the minimum separation to a smaller value fixes the issue.

WhenLifeHandsYouLemons, 2023-06-30:
Doing some final stress tests using the pygame version. The image function doesn't work but we aren't able to test that without the physical board.

Closed 2023-06-30.

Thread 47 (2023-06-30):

Set time ranges for display

WhenLifeHandsYouLemons, 2023-06-30:
Set time and day ranges for when the board should be turned on.

It should be only on weekdays from 8:00AM to 4:30PM most likely as that's the time people would most likely walk past it.

WhenLifeHandsYouLemons, 2023-07-02:
Got it working on the PyGame version. Only small issue is that the time range has to be at different hours. If it starts and ends in the same hour, it won't stop displaying after the end time.

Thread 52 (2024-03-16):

Fix image formatting

WhenLifeHandsYouLemons, 2024-03-16:
Make the images flow better on the website when viewed on smaller screens.

Closed 2024-03-28.

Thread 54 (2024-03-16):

Wrong code for running test version

WhenLifeHandsYouLemons, 2024-03-16:
The code under [this heading](https://github.com/WhenLifeHandsYouLemons/LED-Light-Wall#testing-version) has the wrong code for entering the folder to run the *pygame* testing version.

Closed 2024-03-22.

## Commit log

2023-05-24 Added 3D Models
    [LED Lights 3D Model.blend, LED Lights Shell Demo.blend, LED Lights Shell v2.stl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]
2023-05-29 Flipped board to display text properly
2023-05-31 Removed non-documentation files
    [LED Lights 3D Model.blend, LED Lights Shell Demo.blend, LED Lights Shell v2.stl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]
2023-06-04 Moved 3D models from main branch
    [LED Lights 3D Model.blend, LED Lights Shell Demo.blend, LED Lights Shell v2.stl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]
2023-06-28 Create Circle Algorithm Explanation.md
    It was here before, but we removed it as it wasn’t useful with the NeoPixel buffer module. Then we decided to make it compatible with our precomputation functions so we had to implement it ourselves.
